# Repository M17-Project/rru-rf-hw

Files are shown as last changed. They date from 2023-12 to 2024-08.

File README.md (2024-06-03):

[][cc-by-nc-sa]

# rru-rf-hw
Remote Radio Unit RF board.

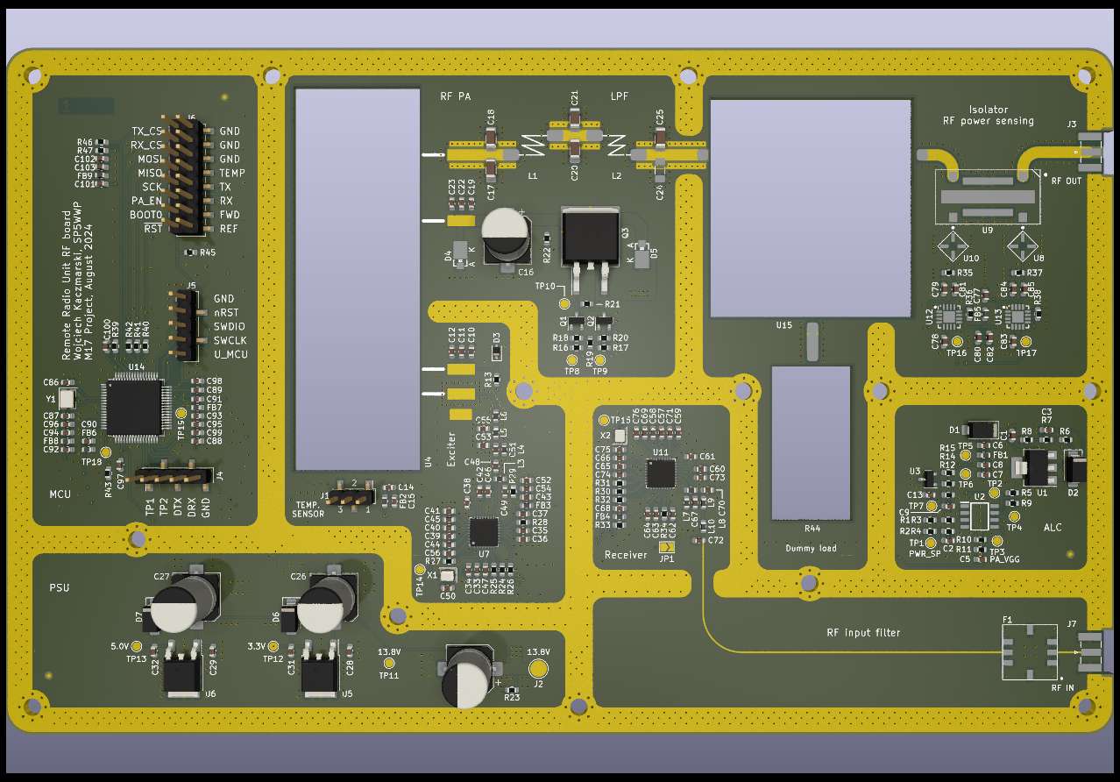
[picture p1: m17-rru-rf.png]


## What is it?
An FM repeater in a milled aluminum chassis. Built around a pair of [CC1200 chips](https://www.ti.com/product/CC1200) from Texas Instruments and an RF power amplifier module.
Revision A with CC1200 RF front-ends supports various FM-based modes, including M17 and AFSK.

## Quick fact sheet
RF power module - [RA60H3847M1](https://www.mitsubishielectric.com/semiconductors/hf/products/datasheet/ra60h3847m1.pdf)<br>
RF output power - 1..60W continuous, up to 80W with lower duty cycle<br>
Frequency range - 420..450MHz<br>
Frequency error - <0.5 ppm over -40 to +85°C range<br>
Supply voltage - 13.8V DC<br>
Power consumption - <150W at 60W RF out<br>
Load mismatch immunity - continuous over the whole VSWR range (built in RF isolator)<br>
Harmonic content - 2nd <-40dBc, 3rd <-55dBc (435MHz at 48.3dBm)<br>
Mode support: analog FM, M17, (A)FSK<br>
Circulator:  WH3538X-1, 400..470MHz (microstrip)<br>
Dummy load: Anaren [J100N50X4B](https://www.mouser.pl/datasheet/2/21/J100N50X4B-3364610.pdf)<br>

## Firmware
A basic, "crash-test" frmware template is available [here](https://github.com/M17-Project/rru-rf-fw).

### Flashing the MCU over UART
- Build the firmware using CubeIDE
- Copy the .bin file over to Raspberry Pi
- Run `stm32flash -v -R -i "-539&-529&539,529,:-539,-529,529" -w rru-rf-fw.bin /dev/ttyAMA0`

In case of problems, see [this](https://github.com/M17-Project/rpi-interface?tab=readme-ov-file#flashing-the-target-device-cc1200-hat) for some additional explanation.

## Chassis
Milled aluminum chassis is required. A reference design can be obtained from a [separate repository](https://github.com/M17-Project/rru-rf-chassis).

## Revision history
### Revision A
Initial revision.

### Revision B
* Switched mode voltage regulators have been replaced with linear.
* Added a buffer between the 40 MHz reference TCXO and transceiver ICs.
* Added bleeder resistors at the RF PA and 13.8V power supply.
* Slightly improved ALC circuit.
* Reduced N-connector cutouts (4.5mm down to 2mm).
* Added decoupling capacitor arrays at both RF PA's supply and VGG pins.
* DA15 connector now has MCU's BOOT0 signal available at pin 13.
* Bodge wire mod is no longer required, as both baseband trigger signals are now routed to the MCU.

### Revision C
* Added a lowpass filter after the RF PA stage
* Added a bandpass filter at the RF input
* TX and RX blocks are now clocked independently
* Pull-down resistor at TP2 (BOOT1)

## License
This work is licensed under a
[Creative Commons Attribution-NonCommercial-ShareAlike 4.0 International License][cc-by-nc-sa].

[][cc-by-nc-sa]

[cc-by-nc-sa]: http://creativecommons.org/licenses/by-nc-sa/4.0/
[cc-by-nc-sa-image]: https://licensebuttons.net/l/by-nc-sa/4.0/88x31.png
[cc-by-nc-sa-shield]: https://img.shields.io/badge/License-CC%20BY--NC--SA%204.0-lightgrey.svg

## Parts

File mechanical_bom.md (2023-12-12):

|Name |PN |Qty |
|---|---|---|
|DA15 connector |DA15S064TLF |1 |
|female N connector |CONN002-W |2 |
|EMI feedthrough filter |2499-003-X5W0-103ZLF |1 |
|M3x5 screw |generic |14 |
|M3x14 screw |generic |4 |
|M3x6 screw |generic |10 |
|M2.5x4 screw |generic |1 |

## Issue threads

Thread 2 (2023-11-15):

RF PA temperature sensor's range extension

sp5wwp, 2023-11-15:
LMT87's temperature range can be extended a bit by supplying it with 5 instead of 3.3V.

sp5wwp, 2024-01-18:
Fixed in 636a110.

Closed 2024-01-18.

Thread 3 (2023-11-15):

Linear voltage regulators instead of switched-mode

sp5wwp, 2023-11-15:
Consider using linear voltage regulators for 3.3 and 5V lines.

sp5wwp, 2024-01-08:
`KF50BDT` and `KF33BDT` are good candidates.

sp5wwp, 2024-01-19:
Fixed in 727ba27.

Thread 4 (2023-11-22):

N connector cutouts

sp5wwp, 2023-11-22:
PCB cutouts are 4.5mm deep now, they can be reduced to 2mm.

Workaround:
Use a 3-4mm long piece of copper wire to solder the N connector's pin to the PCB pad.

sp5wwp, 2024-01-18:
Fixed in 636a110.

Closed 2024-01-18.

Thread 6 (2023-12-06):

Hardware Choices

tomhajjar, 2023-12-06:
1. Is the unit Full or Half Duplex? If Half, why no T/R switch?

2. Why use a bi-directional coupler and log amps on TX output? APC only needs a resistive divider feeding a detector IC like LTC5505.

3. Why use an output isolator? The RA60H3847 can handle fairly high VSWR.

sp5wwp, 2023-12-08:
1. Full duplex with 2 ports. No T/R switch needed.
2. Bi-directional coupler is used to measure SWR.
3. "Fairly high SWR" is not enough, we wanted the output to be bulletproof.

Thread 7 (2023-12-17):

RF input and output stage improvements

sp5wwp, 2023-12-17:
1. Replace `L11`, `C64`, `C63`, and `L10` with a legit bandpass (or lowpass) filter - RBP-440+, LFCN-490+?
2. Put an ESD protection device close to the RX N connector - SESD0402X1UN?
3. Add a lowpass filter between the RF PA and circulator.

sp5wwp, 2024-01-18:
This is for rev. C.

sp5wwp, 2024-03-13:
3. is being worked on.

sp5wwp, 2024-04-04:
3. Done in [4926947](https://github.com/M17-Project/rru-rf-hw/commit/4926947ab17ab5175633e2806dfe3566c8cfa8d8).

sp5wwp, 2024-04-05:
All but 2 fixed in [3db3335](https://github.com/M17-Project/rru-rf-hw/commit/3db3335a4e87a1f32e75a32e3673d100e865a612).

Closed 2024-04-05.

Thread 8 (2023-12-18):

Sampling rate issue

sp5wwp, 2023-12-18:
MCU has to know when to send/read baseband samples from the transceivers. Now, the sample clock is run at the MCU side at 24kHz, and causes occasional sample drops and desynchronization.

Solution (updated Jan 5, 2024):
Connect GPIO2 pin of the transmitting CC1200s to the MCU's EXTI pins, thus letting the TX dictate the baseband transfer speed.
TX GPIO2 (pin 4 of `U7`) -> MCU PA8 (pin 41 of `U14`)

sp5wwp, 2023-12-19:
New firmware has a `#define` to handle the bodge wire mod.

ferdem, 2023-12-19:
unsubscribe

Wojciech Kaczmarski ***@***.***>, 19 Ara 2023 Sal, 16:44
tarihinde şunu yazdı:

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

--
Fatih Erdem

sp5wwp, 2024-01-05:
The new `rpi-interface` branch supports the bodge wire mod without the need of having any #defines.

MCU passes baseband samples to the transmitter at the programmed rate (1.5*16=24kHz), trigger signal is provided by the CC1200. The receiver's `CLKEN_CFM` clock signal is always about 75.7582kHz, regardless of the sample rate setting. Baseband samples from the receiver are therefore read at a rate dictated by TIM7.

sp5wwp, 2024-01-18:
TX sample clock fixed in 636a110.

Closed 2024-01-18.

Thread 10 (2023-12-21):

nRST line pulldown

sp5wwp, 2023-12-21:
Increase R44 to 47..100k.

sp5wwp, 2024-01-18:
Fixed in 636a110. Additionally, 2 other resistors were changed to 22k (R45 and R46).

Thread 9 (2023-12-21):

ALC stability issue above 40dBm

sp5wwp, 2023-12-21:
Problem:
Output level instability, probably caused by insufficient PA drive.

Fix:
- Remove C2 (or replace by lower value capacitor, like 220pF).
- Bypass R5 with a 100nF capacitor to extend ramp-up time.
- Add MMIC preamplifier between the exciter and PA - [GVA-83+](https://www.minicircuits.com/pdfs/GVA-83+.pdf) looks OK.

sp5wwp, 2024-01-01:
Add an RC lowpass between U1B and VGG.

sp5wwp, 2024-01-18:
636a110 has a potential fix. Might reopen this issue if the problem persists.

Closed 2024-01-18.

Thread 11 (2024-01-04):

BOOT0 line at the DA15 connector

sp5wwp, 2024-01-04:
It would be nice to expose STM32's BOOT0 pin at the DA15 connector to enable remote MCU reprogramming.

sp5wwp, 2024-01-18:
Fixed in 636a110.

Closed 2024-01-18.

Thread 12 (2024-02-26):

Fix programming over USART1

sp5wwp, 2024-02-26:
Since the `TP2` (PB2, pin 28) is shared with `BOOT1`, add a pull-down resistor there.

sp5wwp, 2024-04-04:
Fixed with [4926947](https://github.com/M17-Project/rru-rf-hw/commit/4926947ab17ab5175633e2806dfe3566c8cfa8d8).

Closed 2024-04-04.

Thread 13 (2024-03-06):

XOSC_Q1 pins left floating

sp5wwp, 2024-03-06:
Connect `XOSC_Q1` pins of both TX and RX CC1200 to GND, as per datasheet, page 6:
`Crystal oscillator pin 1 (must be grounded if a TCXO or other external clock connected to EXT_XOSC is used)`

sp5wwp, 2024-04-04:
Fixed with [4926947](https://github.com/M17-Project/rru-rf-hw/commit/4926947ab17ab5175633e2806dfe3566c8cfa8d8).

Closed 2024-04-04.

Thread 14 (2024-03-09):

CC1200 clocking issues

sp5wwp, 2024-03-09:
40MHz signal reaching CC1200 transceivers has an average rising time of 2.7ns, which exceeds 2ns limit set by the datasheet (see [p. 15](https://www.ti.com/lit/ds/symlink/cc1200.pdf?ts=1709928554703)).

Symptoms: CW signals have spurs at 27..40kHz (both sidebands) at about -40dBc.

Workaround: connect the TCXO's output through a 9.1pF capacitor straight to TX's pin 32. This requires cutting the path between that pin and clock buffer's output.

sp5wwp, 2024-03-13:
One possible solution to that would be to use 2 TCXOs - one for each CC1200.

sp5wwp, 2024-04-04:
Fixed with [4926947](https://github.com/M17-Project/rru-rf-hw/commit/4926947ab17ab5175633e2806dfe3566c8cfa8d8).

Closed 2024-04-04.

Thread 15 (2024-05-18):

RS-485

sp5wwp, 2024-05-18:
Use RS-485 instead of raw 3.3V UART for improved noise immunity.

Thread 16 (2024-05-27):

RF lowpass filter - proposed values

sp5wwp, 2024-05-27:
`L1`, `L2` as described in the schematic:
0.8 mm silver plated copper wire
3 turns
3.2 mm inner diameter
~4 mm length
Resulting inductance should be around 24nH

`C17`, `C18` plus PCB trace stray capacitance (3.8 pF measured): should add up to 6.8 pF. Proposed values: 1.5 + 1.5 pF.
`C20`, `C21` plus PCB trace stray capacitance (3.3 pF measured): should add up to 13 pF. Proposed values: 8.2 + 1.5 pF.
`C24`, `C25` plus PCB trace stray capacitance (4 pF measured): should add up to 6.8 pF. Proposed value: 2.7 pF.

PNs:
`12062A2R7CAT2A` - MLCC, 200V 2.7pF C0G 1206 0.25pF tol.
`12067A1R5CAT2A` - MLCC, 500V 1.5pF C0G 1206 0.25pF tol.
`12067A8R2BAT2A` - MLCC, 500V 8.2pF C0G 1206 0.1pF tol.

sp5wwp, 2024-05-27:
If the values are OK, I'll update the schematic accordingly.

sp5wwp, 2024-08-08:
Added in [f473ff9](https://github.com/M17-Project/rru-rf-hw/commit/f473ff9adecd40cb060c2f3618910c76df8fe21e).

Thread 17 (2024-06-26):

RF PA bias limiting Zener diode

sp5wwp, 2024-06-26:
`D3`'s Zener voltage is 5.1V, maybe it would be wise to replace it with a 4.3 or 4.7V.

sp5wwp, 2024-08-08:
Maximum Vgg is 6V, we could keep the 5.1V Zener diode, but I'm replacing it with 4.7V `MM3Z4V7ST1G`.

Closed 2024-08-08.

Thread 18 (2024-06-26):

License question

sedlund, 2024-06-26:
I see this project is using the 'CC Attribution-NonCommercial-ShareAlike 4.0 International' license.  This is not an OSI approved Open Source license.

M17 project on it's web page says it is an open source project.

How was this license chosen for this project?

When someone donates to M17 can they choose to only fund open source projects?  Is this documented anywhere?

sp5wwp, 2024-06-26:
Thanks for your comments.

>This is not an OSI approved Open Source license.
It doesn't mean that it's not open source. Is the documentation/code available for free to anyone? Yes - for me it's open source.

>M17 project on it's web page says it is an open source project.
Because it is. All our work is available to the general public for free.

>How was this license chosen for this project?
I picked one I liked the most at that time. Since I'm the sole author, I can change them in the future however I desire.

>When someone donates to M17 can they choose to only fund open source projects? Is this documented anywhere?
When donating, the donor gives us a certain amount of money, to sustain the *whole* Project. I don't think our fiscal sponsor allows for funds earmarking per donation.

sp5wwp, 2024-06-26:
`Open source is source code that is made freely available for possible modification and redistribution.`

Which part of this sentence do we violate?

sedlund, 2024-06-26:
Specificlaly the current license states:

```
Section 2 -- Scope.

  a. License grant.

       1. Subject to the terms and conditions of this Public License,
          the Licensor hereby grants You a worldwide, royalty-free,
          non-sublicensable, non-exclusive, irrevocable license to
          exercise the Licensed Rights in the Licensed Material to:

            a. reproduce and Share the Licensed Material, in whole or
               in part, for NonCommercial purposes only; and

            b. produce, reproduce, and Share Adapted Material for
               NonCommercial purposes only.
```

This violates the requirements of the open source definition against discrimination of fields of endeavor - parts 5 and 6 of the [open source definition](https://opensource.org/osd).

sp5wwp, 2024-06-26:
OK: 5. is not violated, while 6. is, deliberately (non-commercial clause). This is exactly how I wanted it to be. Do you have any further comments or questions?

sedlund, 2024-06-26:
I appreciate the clarification.

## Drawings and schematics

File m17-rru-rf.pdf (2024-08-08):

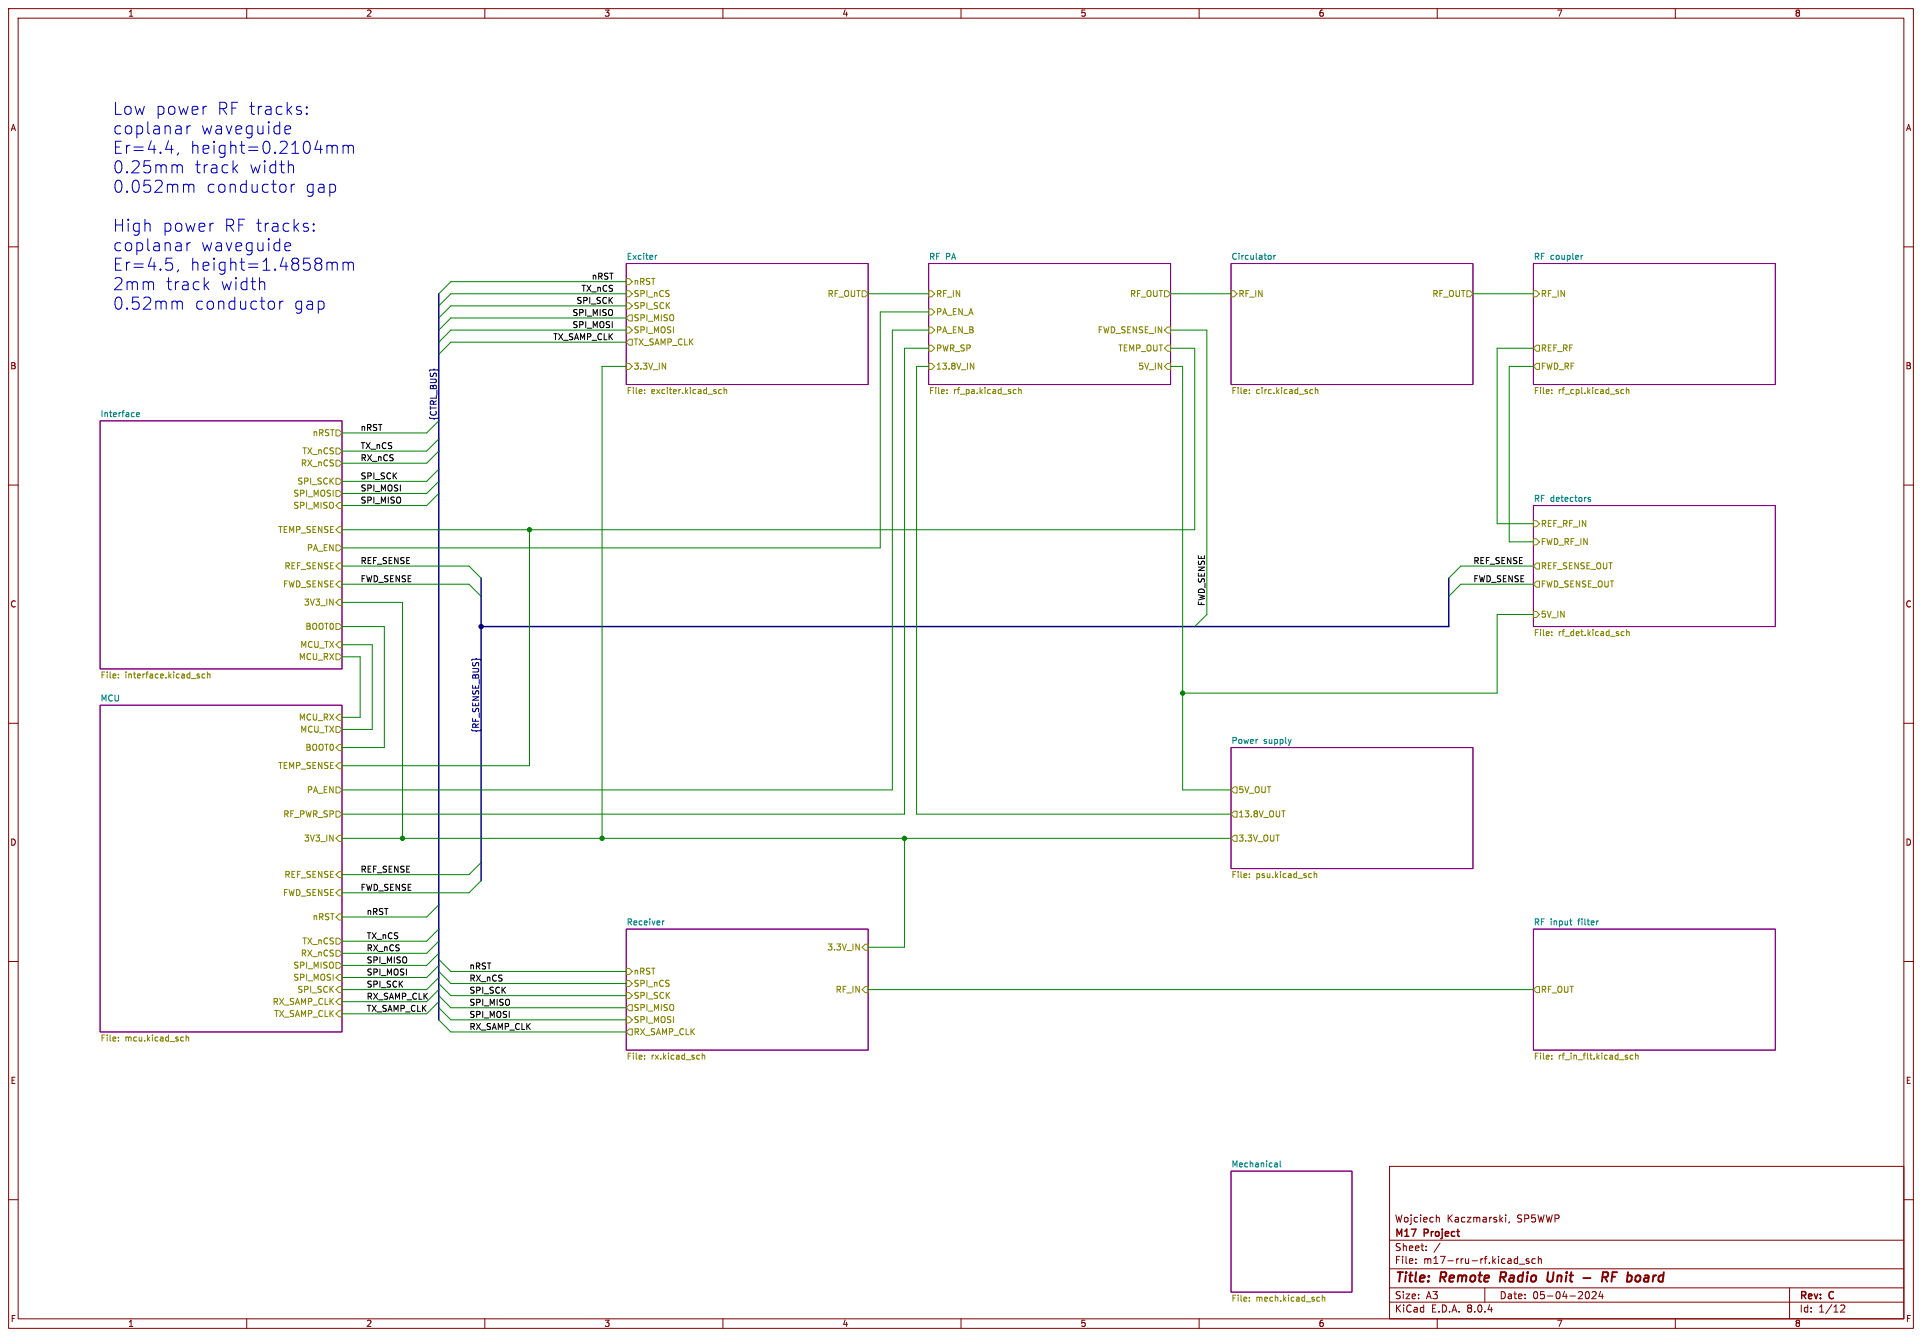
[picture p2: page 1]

nRST SPI_SCK RX_nCS Low power RF tracks:
coplanar waveguide
Er=4.4, height=0.2104mm
0.25mm track width

High power RF tracks:
Er=4.5, height=1.4858mm
2mm track width

5V_OUT Power supply File: psu.kicad_sch

Id: 1/12 Title: Remote Radio Unit - RF board

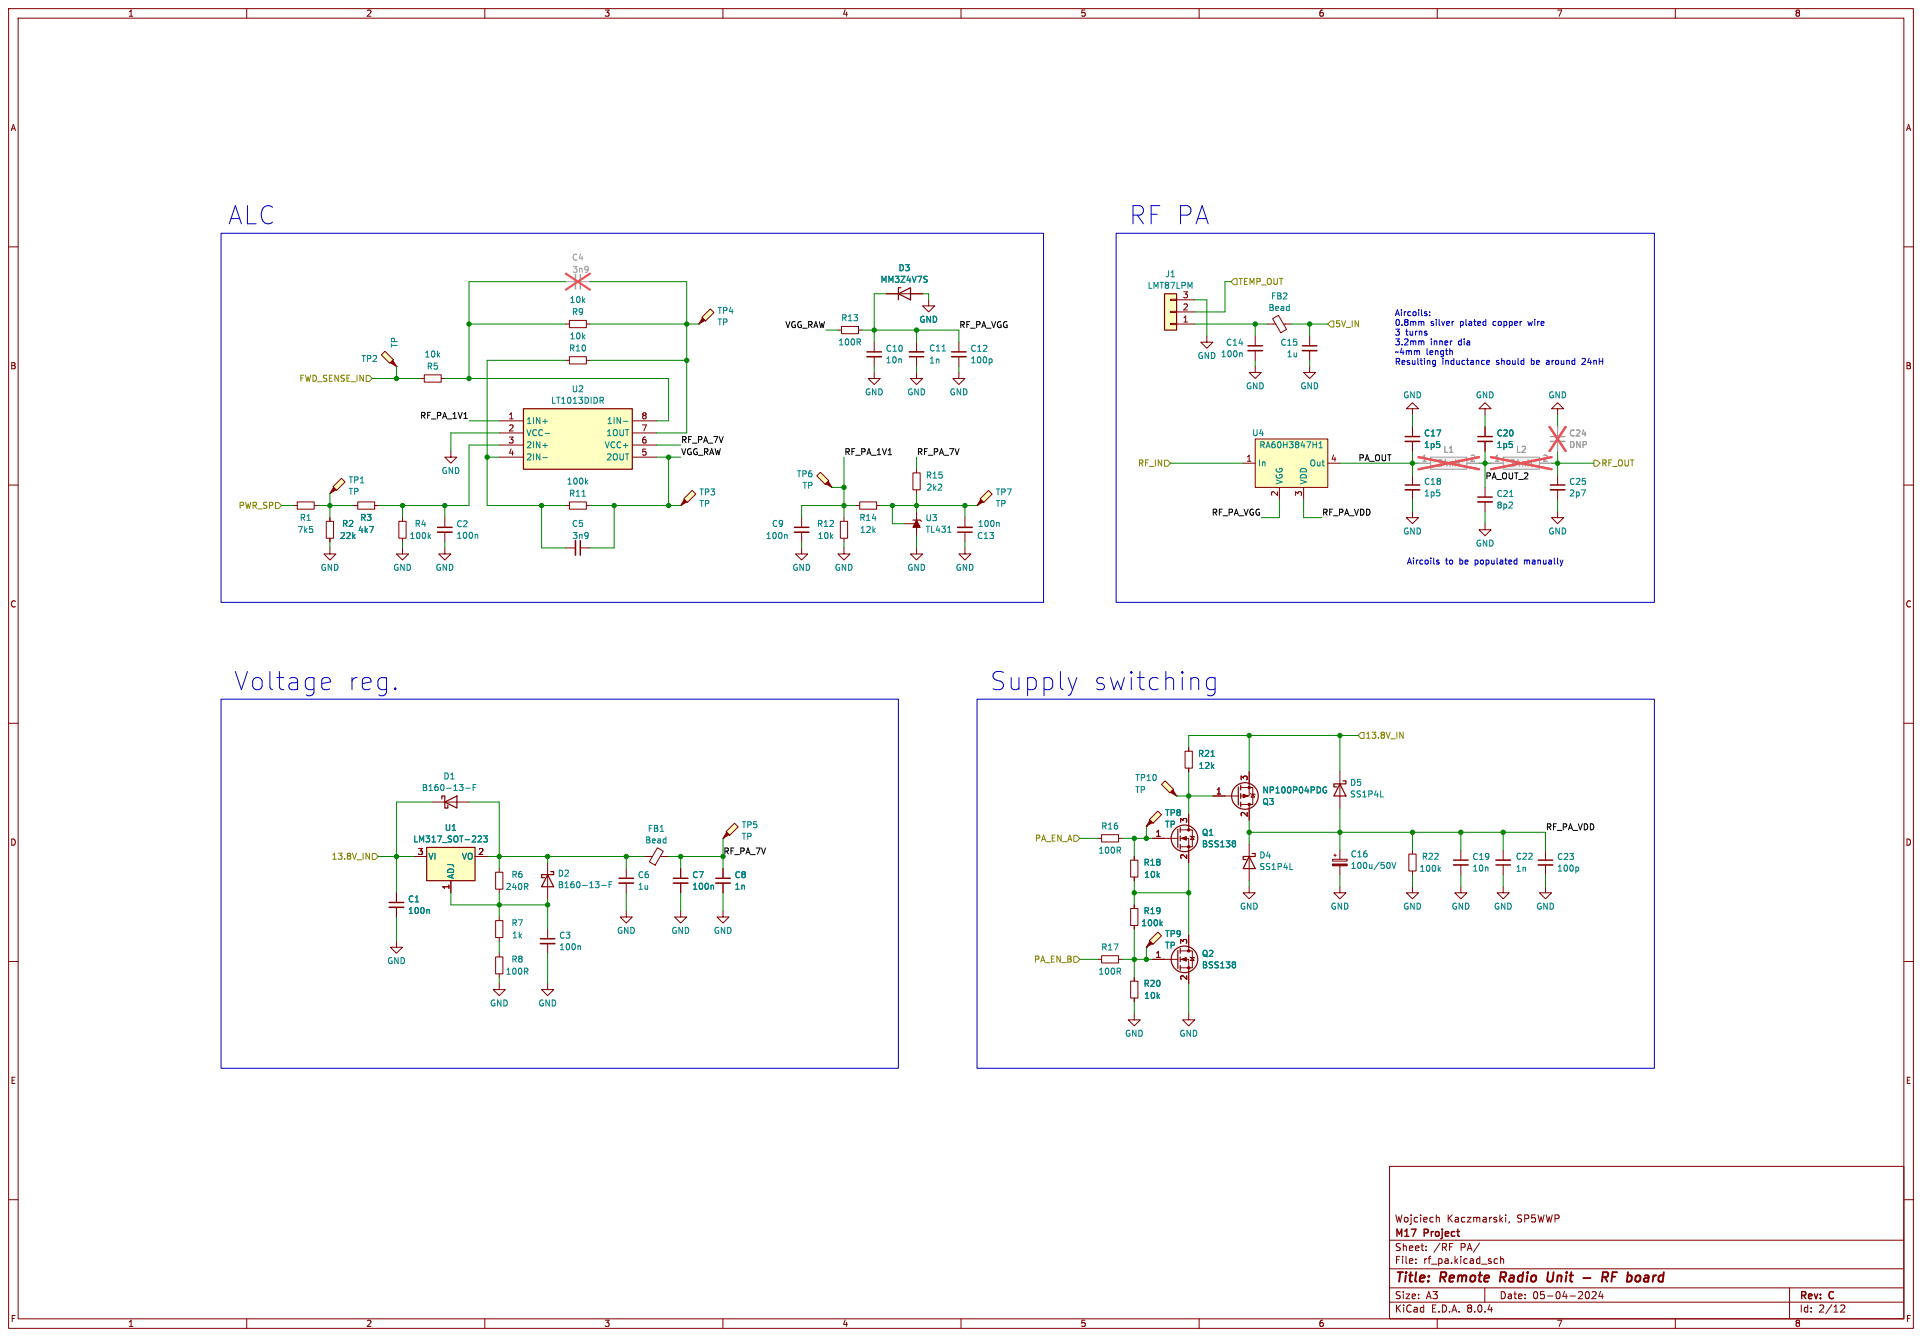
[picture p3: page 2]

Aircoils: 0.8mm silver plated copper wire

3 turns 3.2mm inner dia ~4mm length

Id: 2/12 Title: Remote Radio Unit - RF board

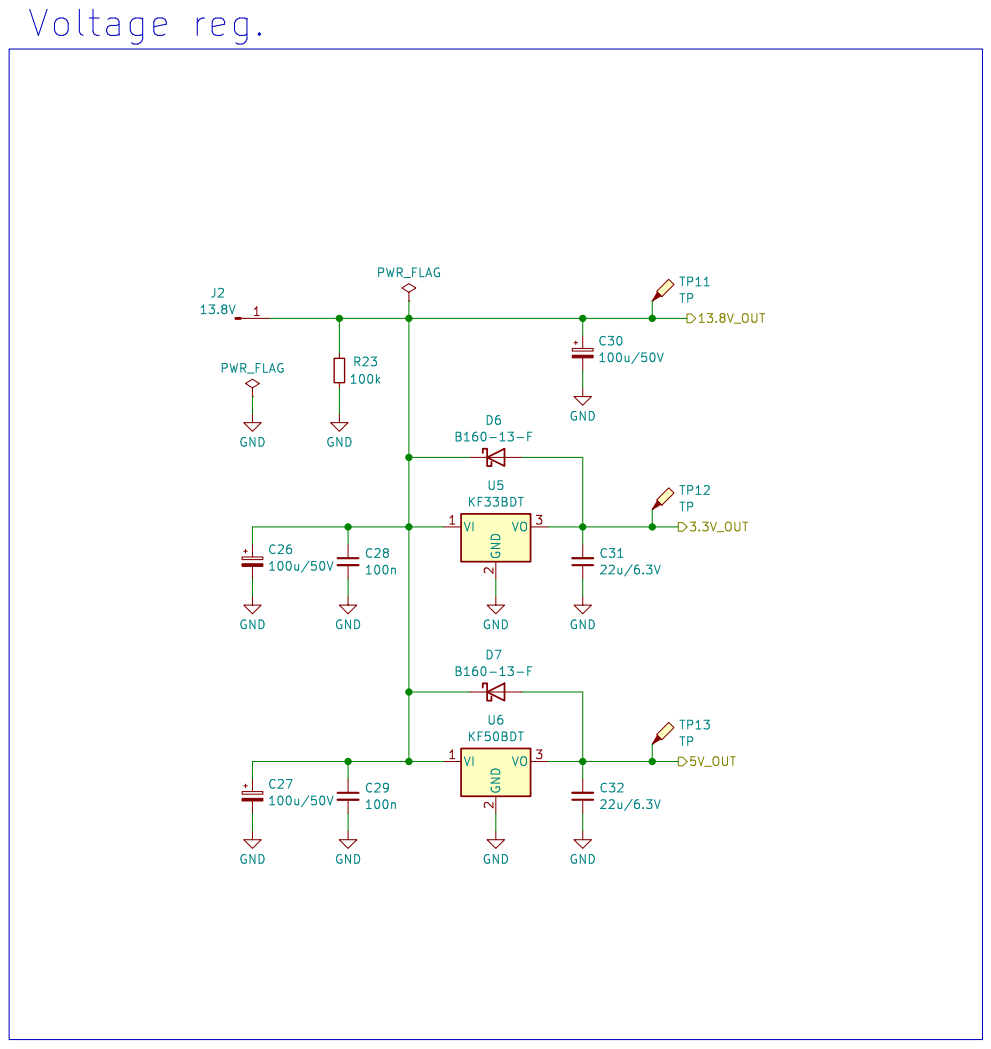
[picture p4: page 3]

2 VO 3 U5 KF33BDT GND GND GND
100u/50V GND

Id: 3/12 Title: Remote Radio Unit - RF board

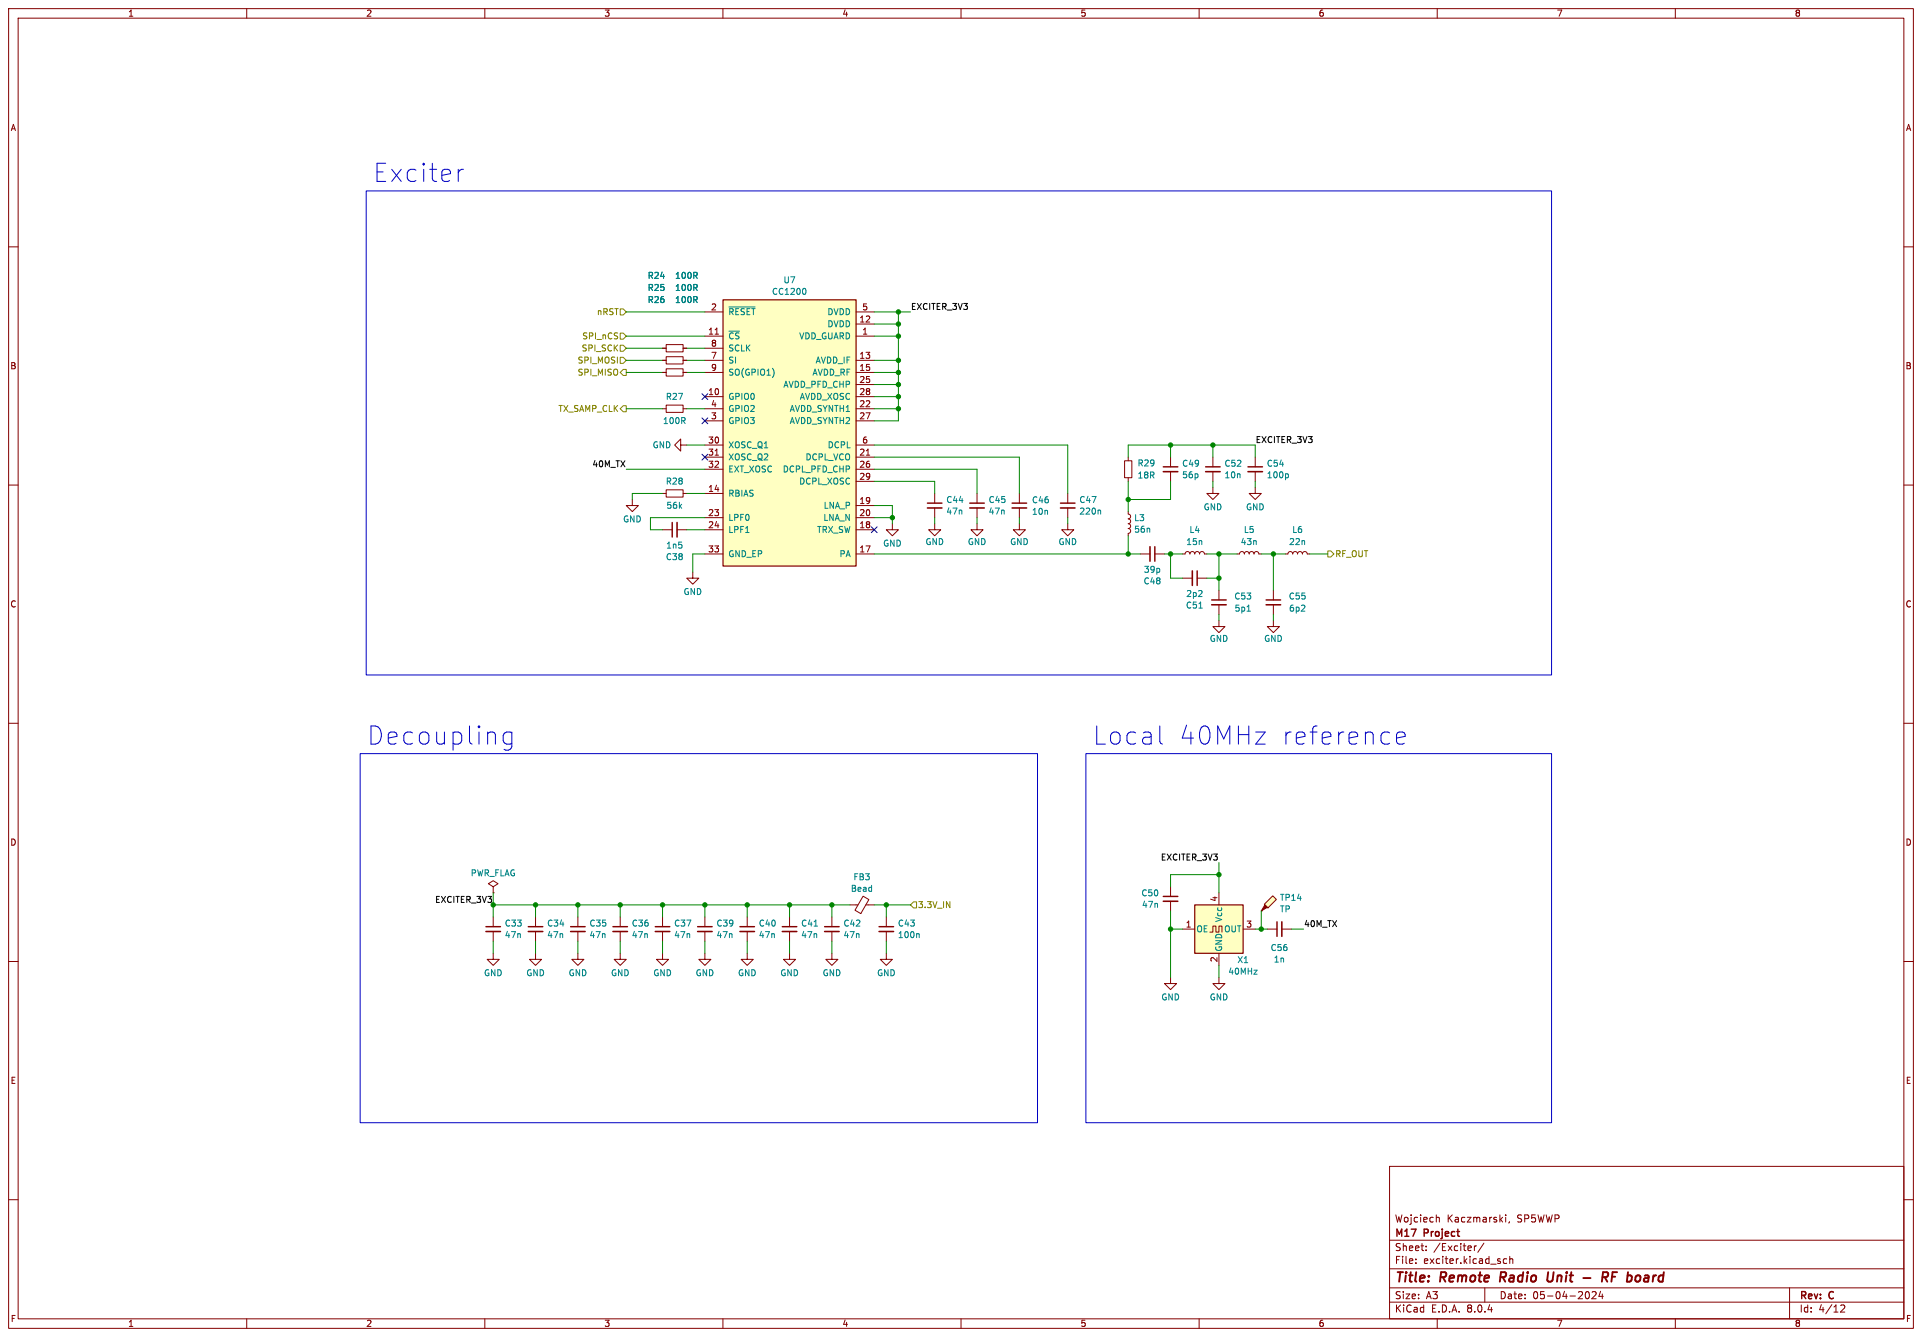
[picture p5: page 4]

Id: 4/12 Title: Remote Radio Unit - RF board

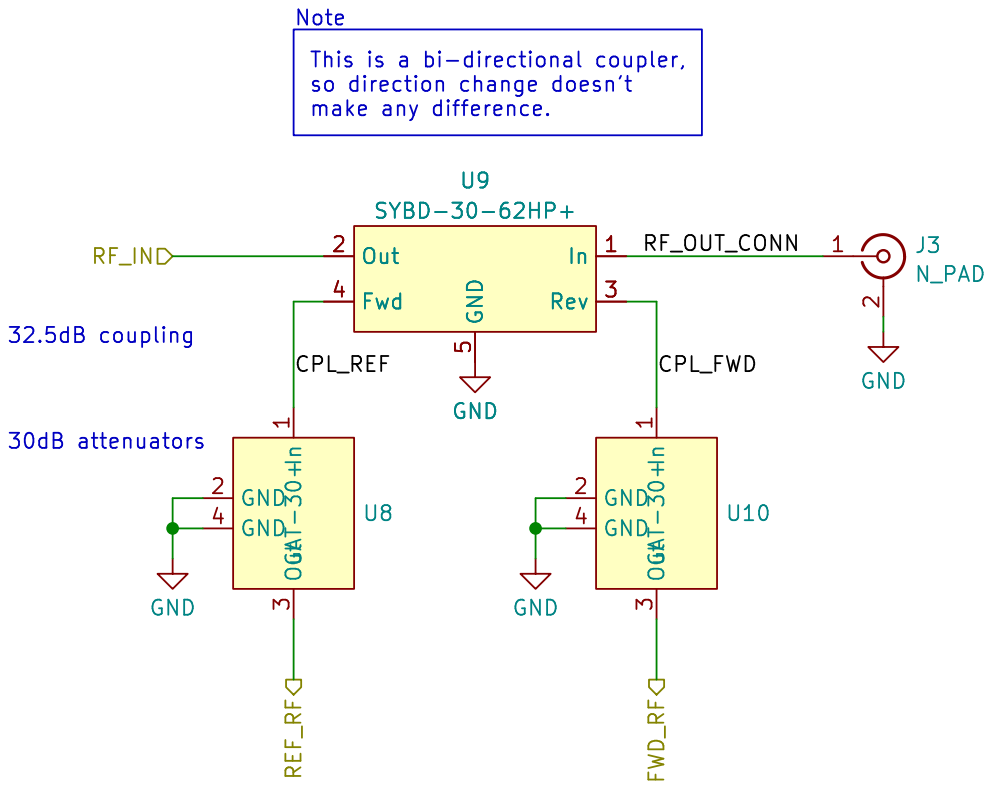
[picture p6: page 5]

1 GND 2 Out 3 GND 4 U8 GAT-30+ FWD_RF RF_IN REF_RF CPL_REF CPL_FWD

1 GND 2 Out 3 GND 4 U10 GAT-30+ GND

Id: 5/12 Title: Remote Radio Unit - RF board

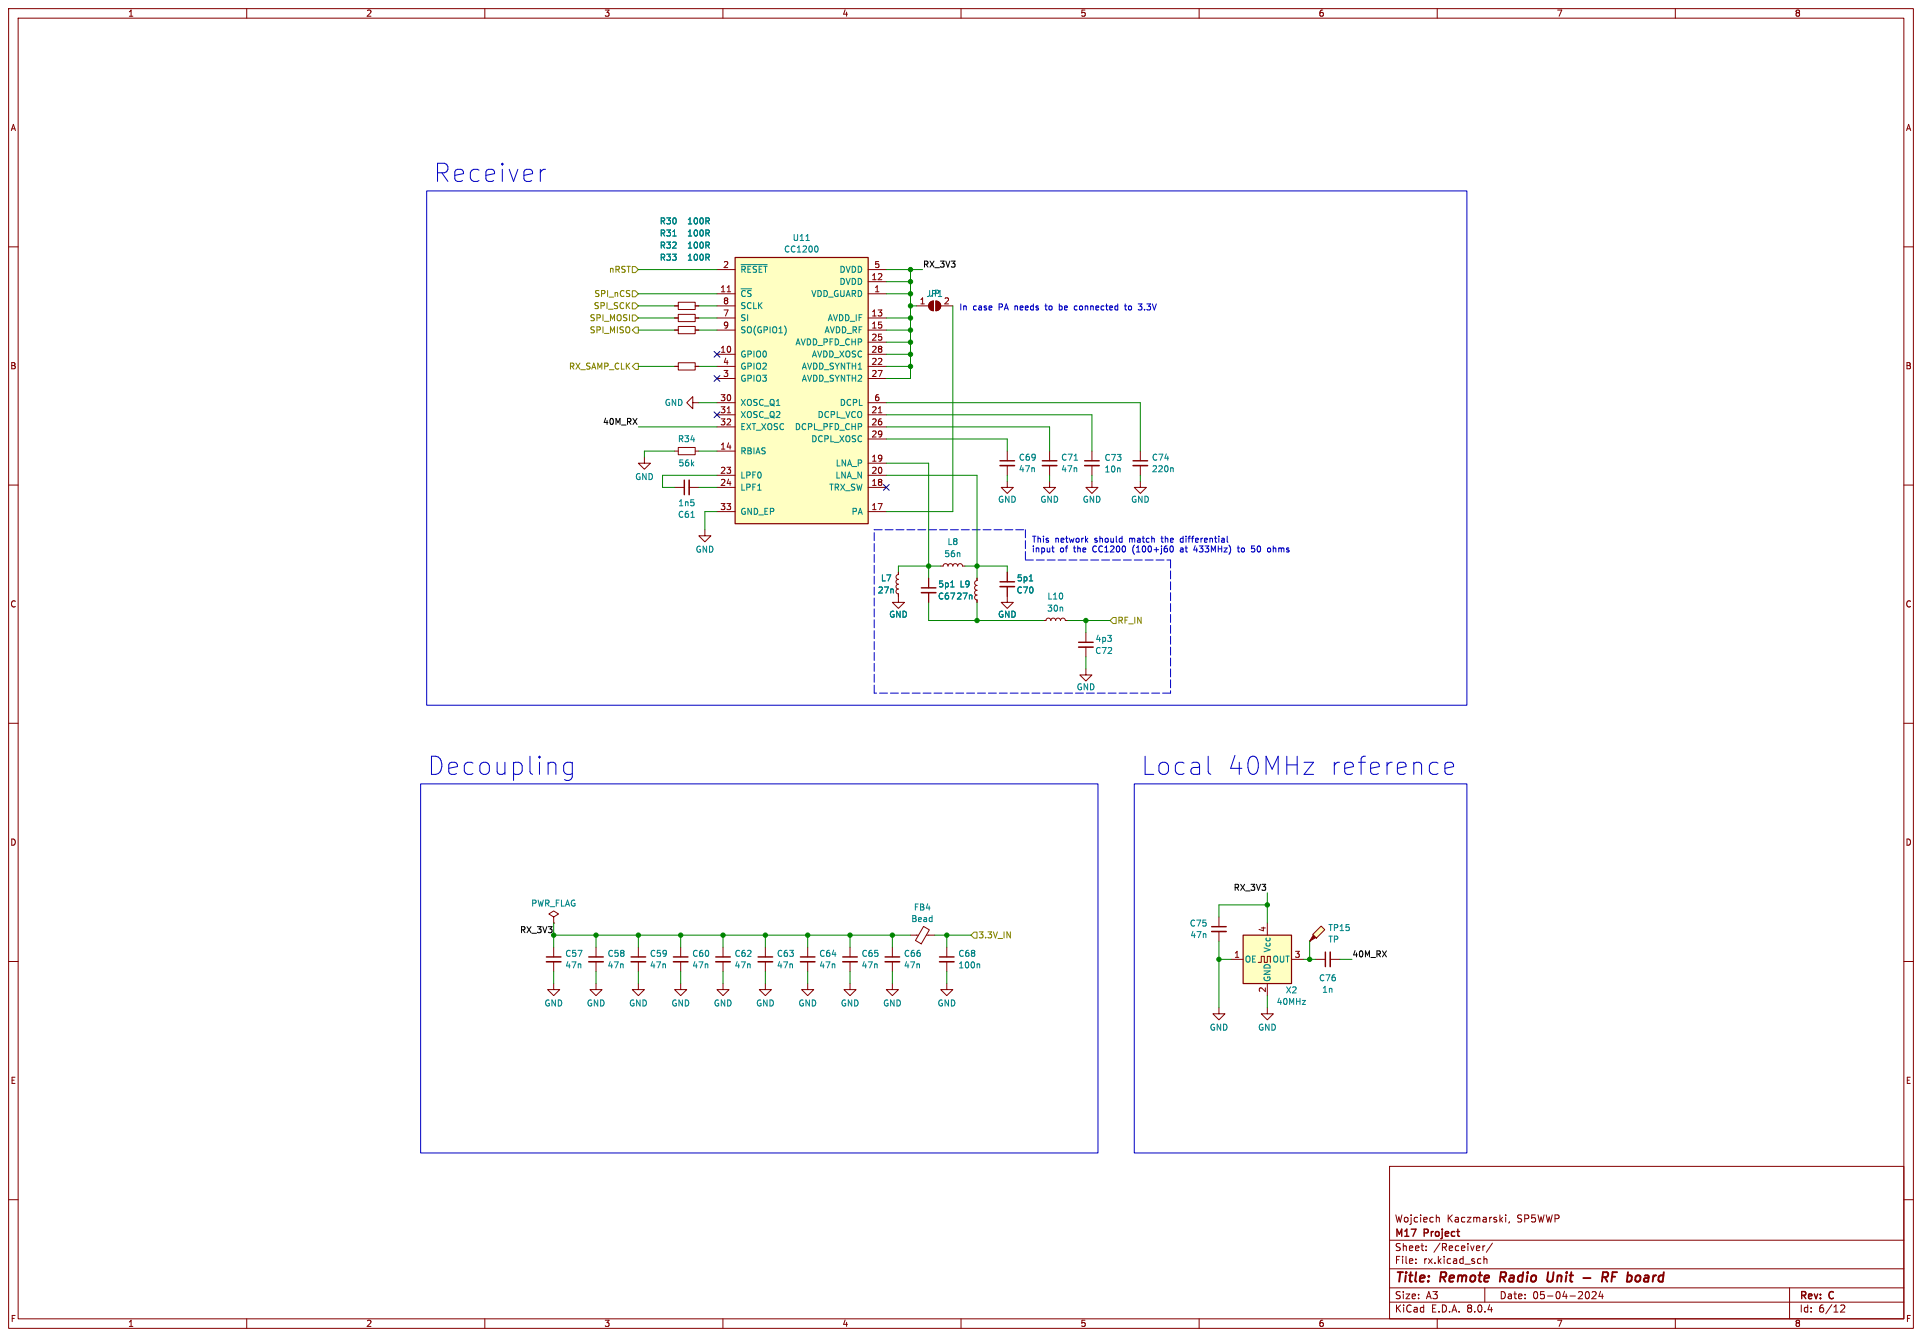
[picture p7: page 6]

This network should match the differential

Id: 6/12 Title: Remote Radio Unit - RF board

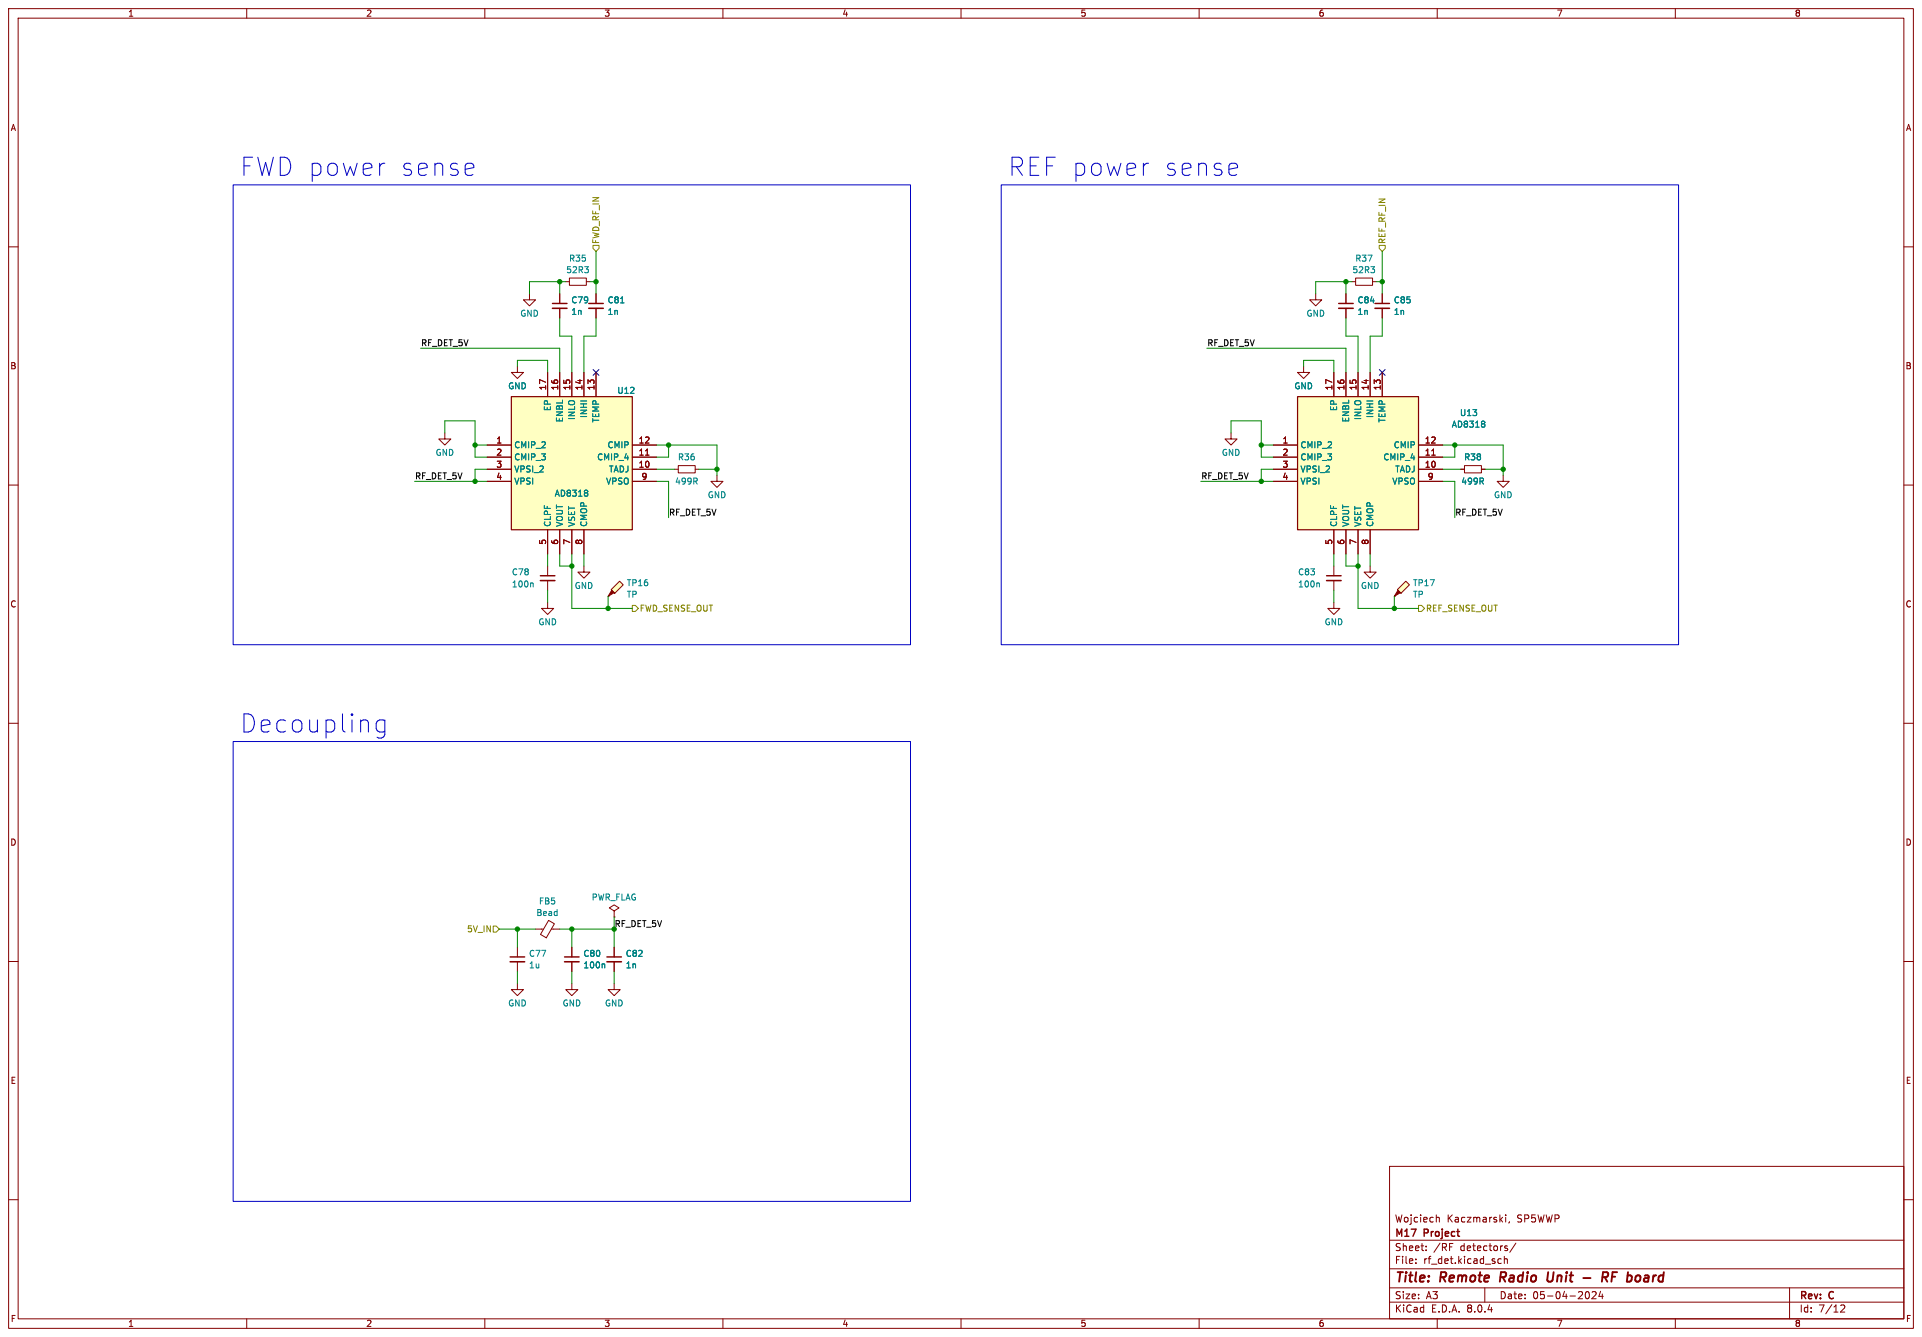
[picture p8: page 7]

Id: 7/12 Title: Remote Radio Unit - RF board

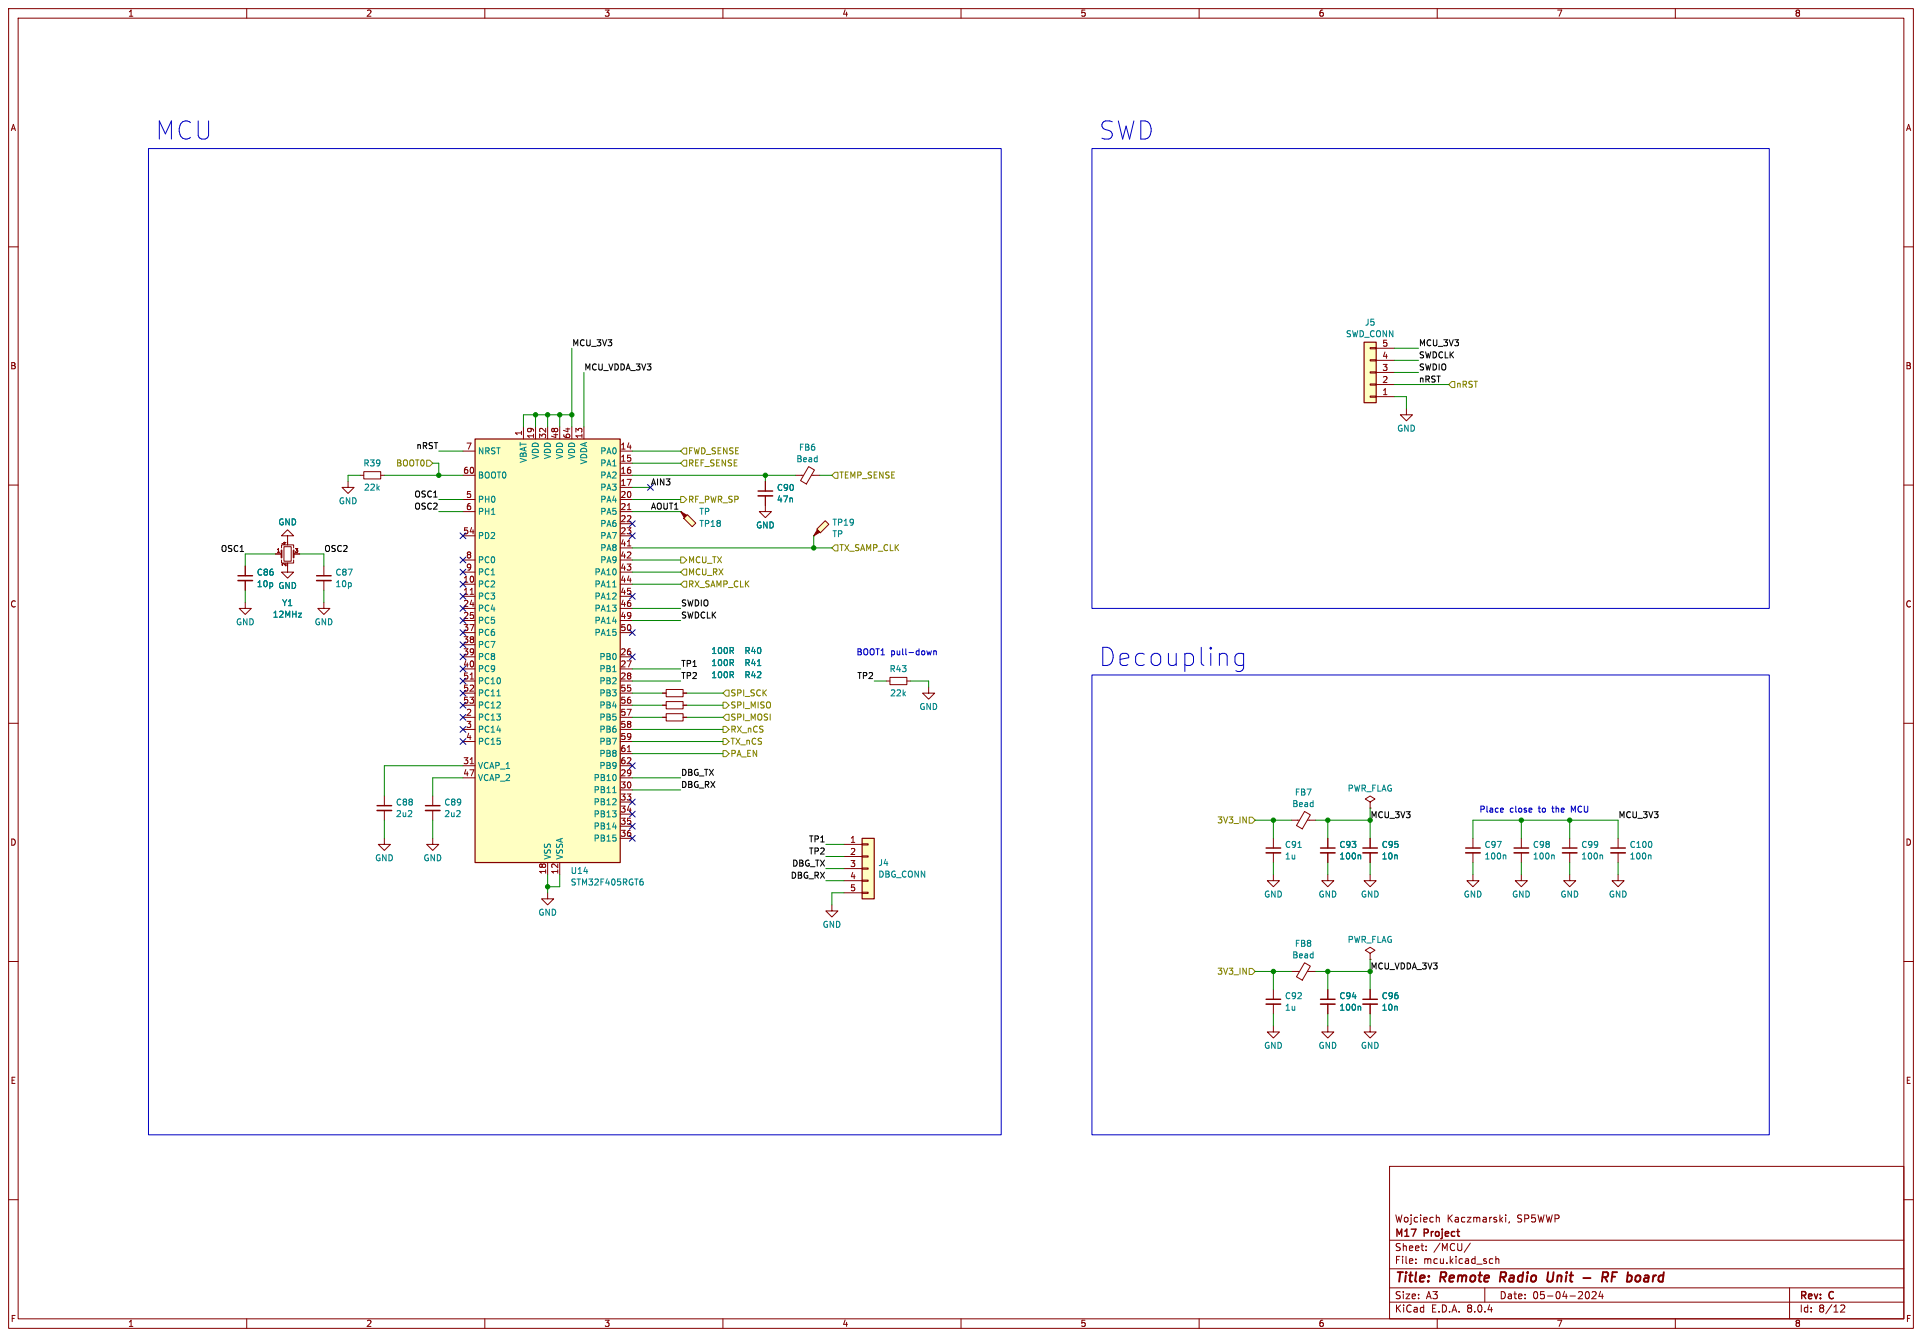
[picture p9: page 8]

1 PC2 10 PC3 11 VSSA 12 VDDA 13 PA0 14 PA1 15 PA2 16 PA3 17 VSS 18 VDD 19 PC13 2 PA4 20 PA5 21 PA6 22 PA7 23 PC4 24 PC5 25 PB0 26 PB1 27 PB2 28 PB10 29 PC14 3 PB11 30 VCAP_1 31 VDD 32 PB12 33 PB13 34 PB14 35 PB15 36 PC6 37 PC7 38 PC8 39 PC15 4 PC9 40 PA8 41 PA9 42 PA10 43 PA11 44 PA12 45 PA13 46 VCAP_2 47 VDD 48 PA14 49 PH0 5 PA15 50 PC10 51 PC11 52 PC12 53 PD2 54 PB3 55 PB4 56 PB5 57 PB6 58 PB7 59 PH1 6 BOOT0 60 PB8 61 PB9 62 VDD 64 NRST 7 PC0 8 PC1 9 U14 STM32F405RGT6 C86

Place close to the MCU

Id: 8/12 Title: Remote Radio Unit - RF board

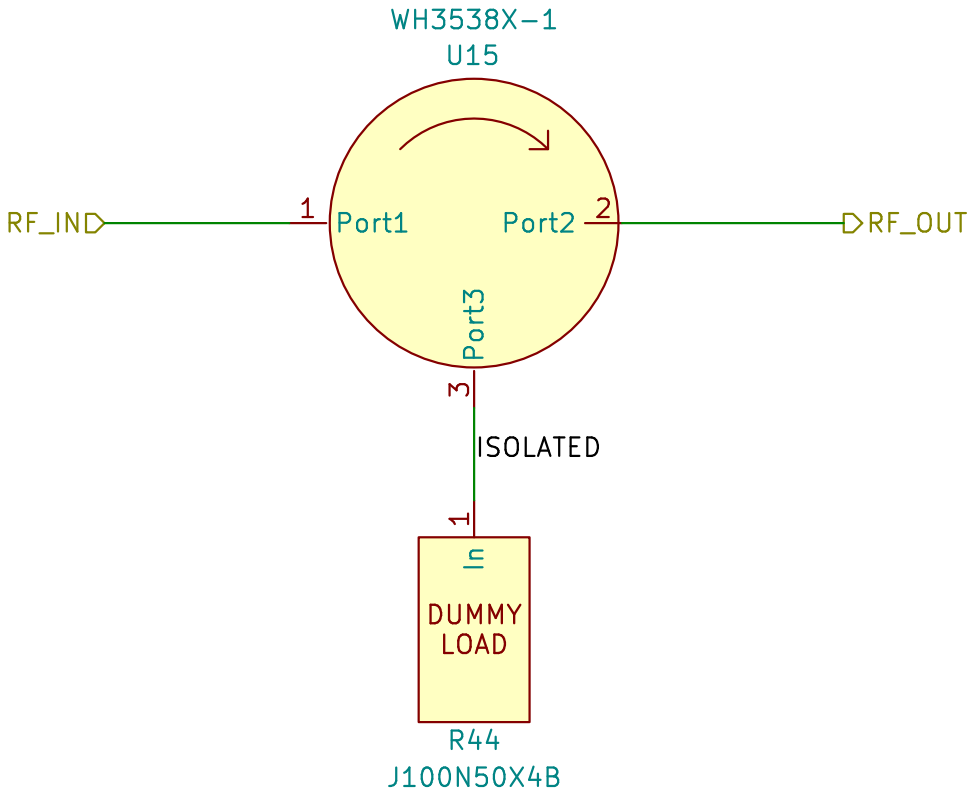
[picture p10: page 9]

Id: 9/12 Title: Remote Radio Unit - RF board

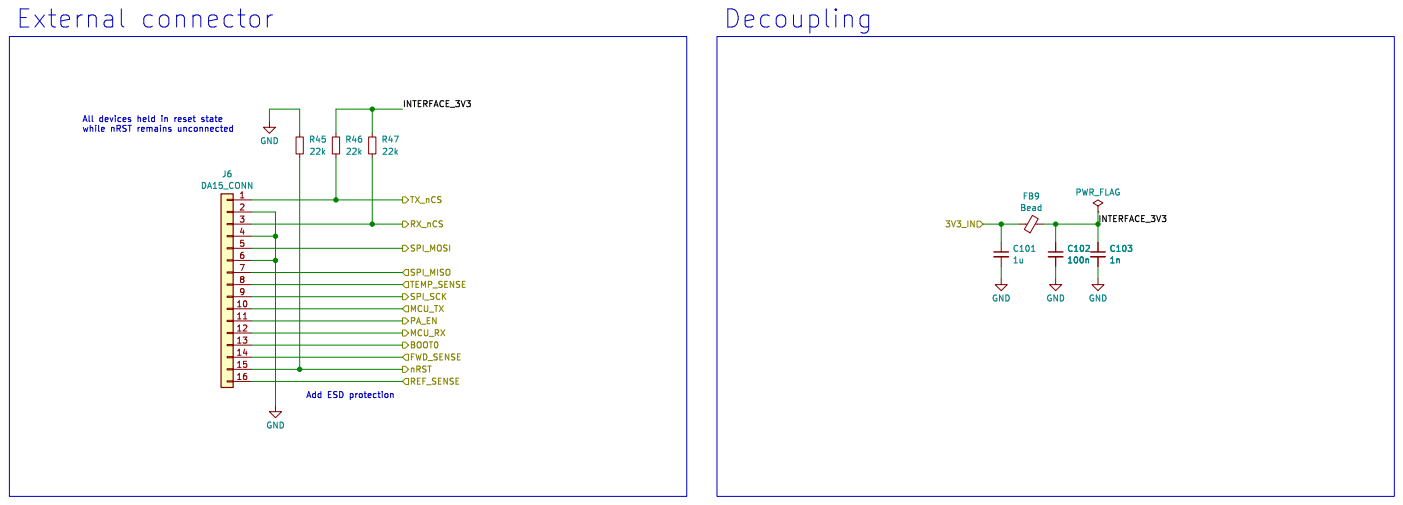
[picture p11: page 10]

Id: 10/12 Title: Remote Radio Unit - RF board

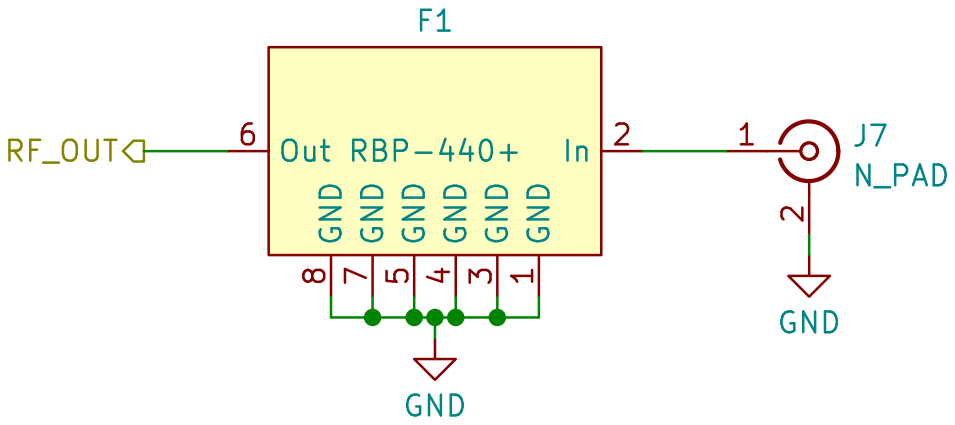
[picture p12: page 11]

Id: 11/12 Title: Remote Radio Unit - RF board

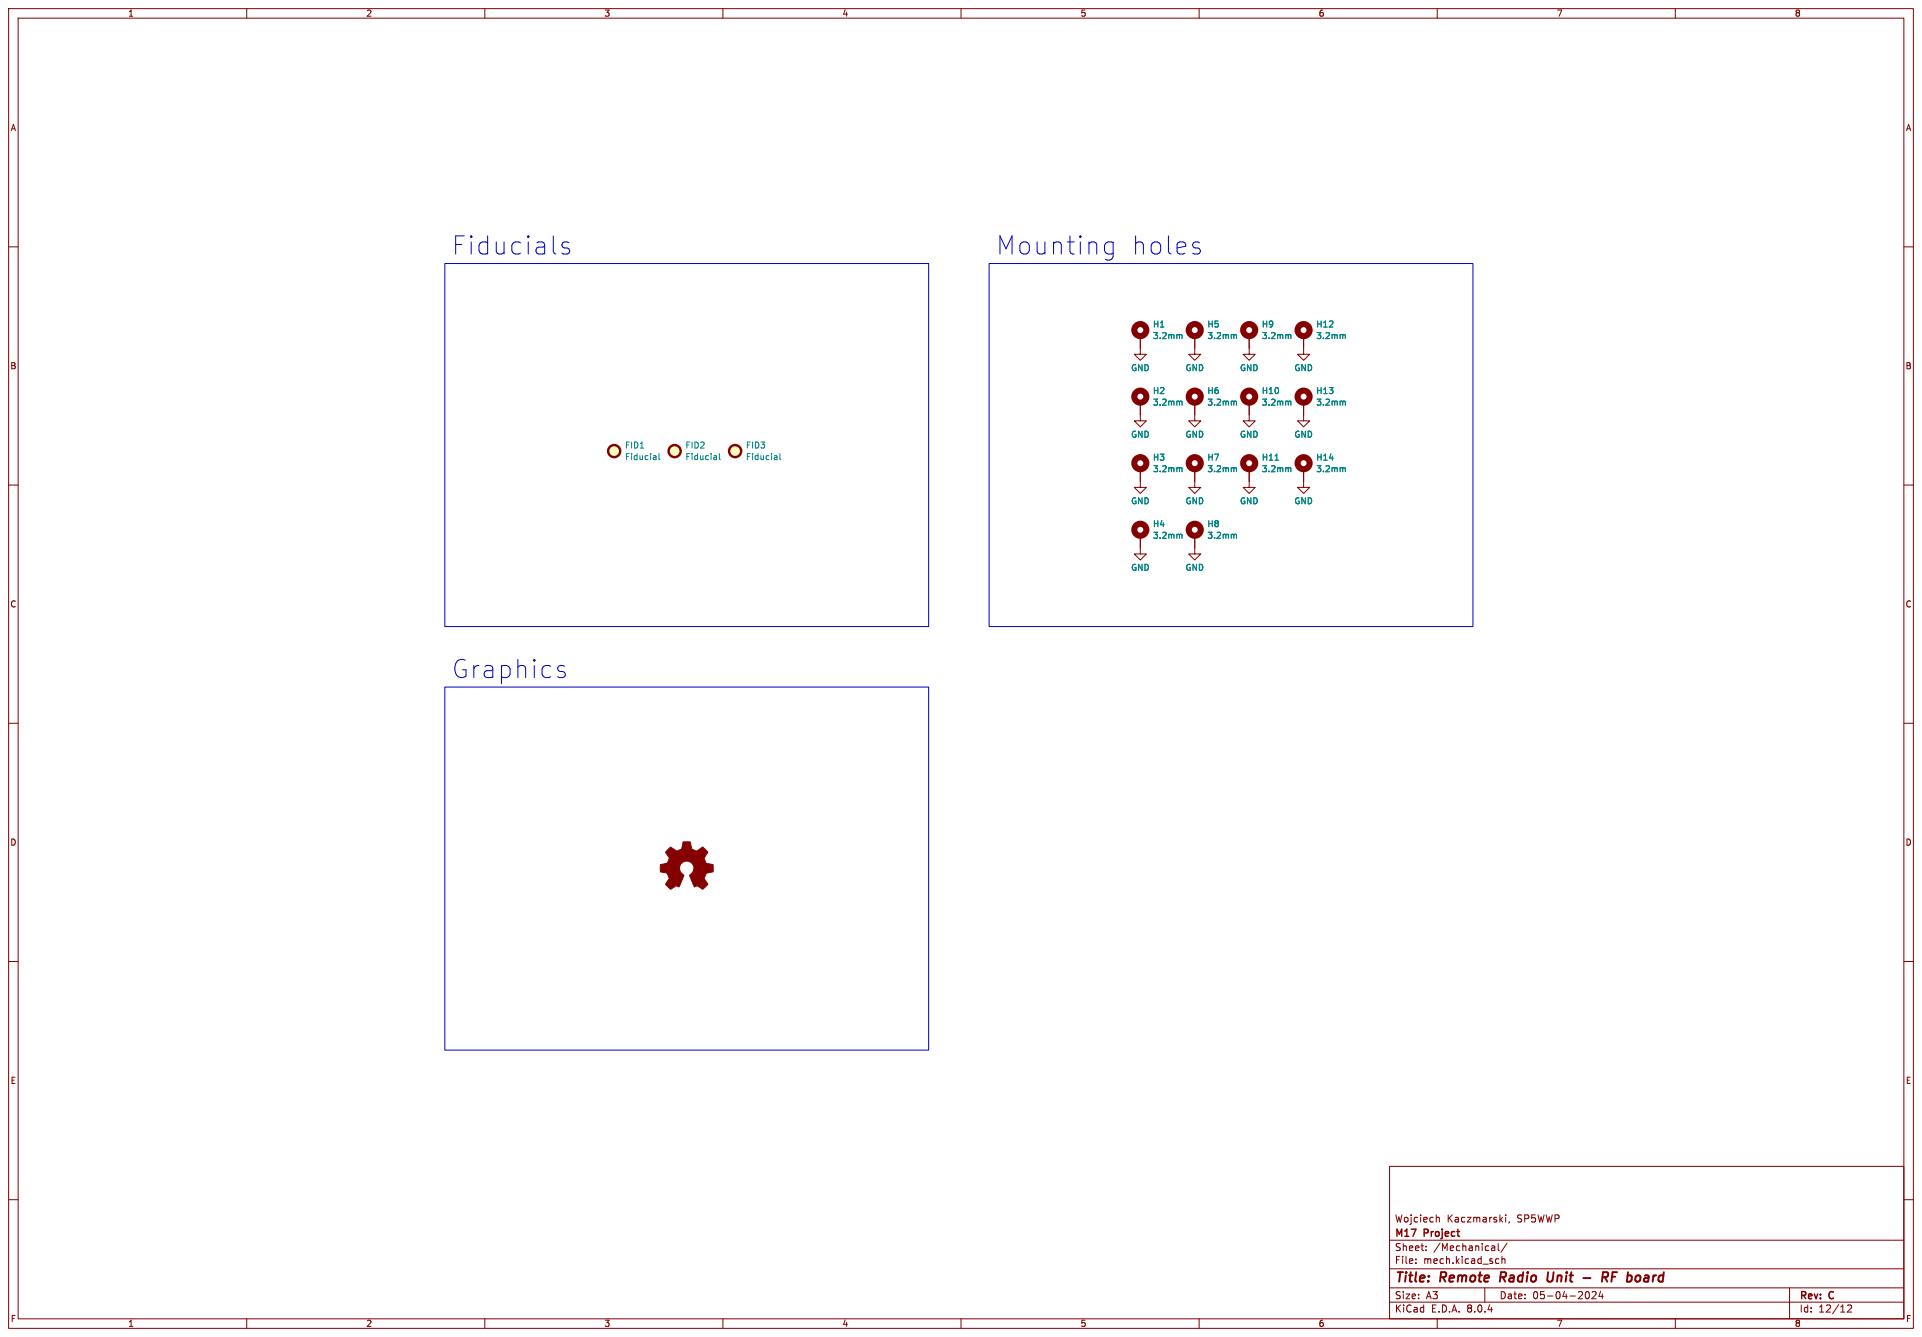
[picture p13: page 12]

Id: 12/12 Title: Remote Radio Unit - RF board

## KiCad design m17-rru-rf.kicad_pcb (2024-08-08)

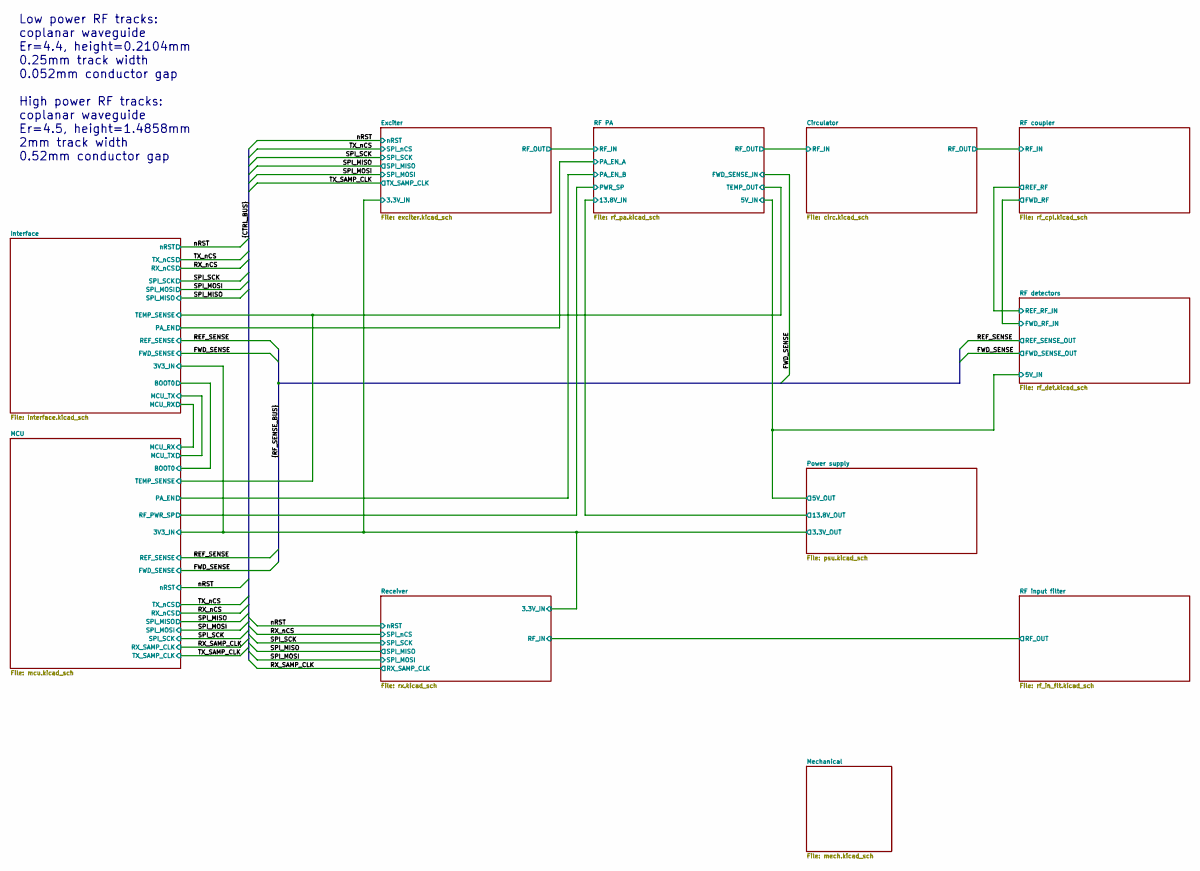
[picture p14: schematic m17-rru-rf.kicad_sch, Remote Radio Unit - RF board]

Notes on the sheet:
Low power RF tracks: coplanar waveguide Er=4.4, height=0.2104mm 0.25mm track width 0.052mm conductor gap High power RF tracks: coplanar waveguide Er=4.5, height=1.4858mm 2mm track width 0.52mm conductor gap

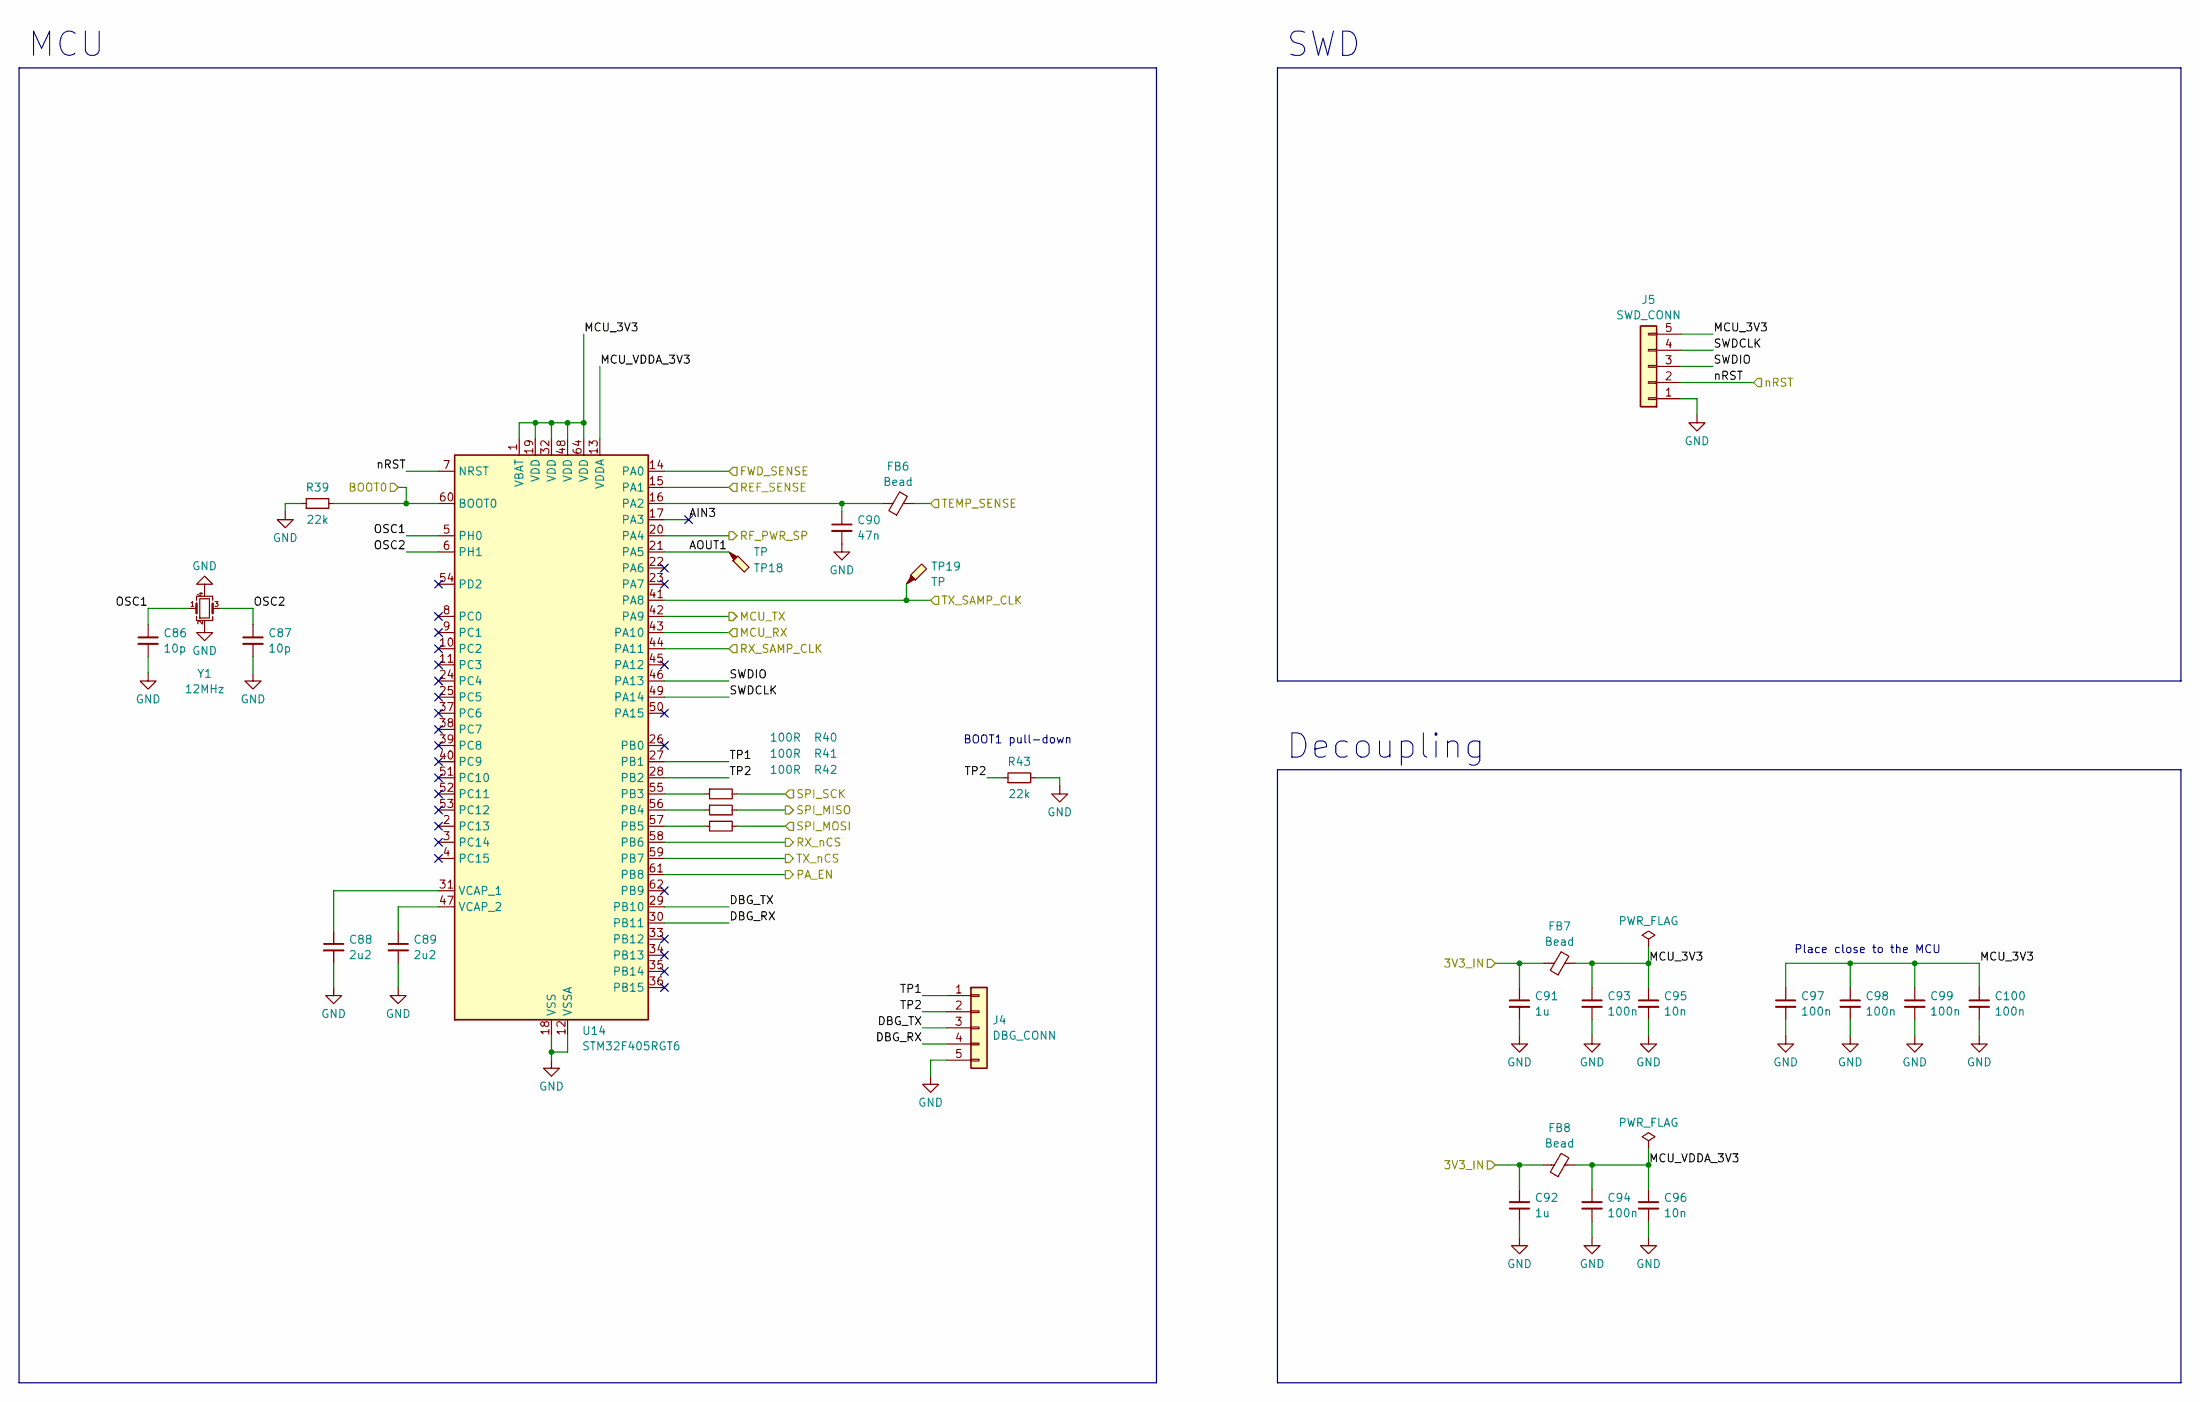
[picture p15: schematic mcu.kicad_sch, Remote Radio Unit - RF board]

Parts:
C86, C87: 10p; C_0603_1608Metric; MPN 06035A100JAT2A
C88, C89: 2u2; C_0603_1608Metric; MPN GRM188R61H225ME11J
C90: 47n; C_0603_1608Metric; MPN C0603C473K5RACTU
C91, C92: 1u; C_0603_1608Metric; MPN CL10B105KB8NQNC
C93, C94, C97, C98, C99, C100: 100n; C_0603_1608Metric; MPN C0603C104M5RAC7411
C95, C96: 10n; C_0603_1608Metric; MPN C0603C103K5RAC7081
FB6, FB7, FB8: Bead; L_0603_1608Metric; MPN BLM18KG601SH1D
J4: DBG_CONN; PinHeader_1x05_P2.54mm_Vertical_SMD_Pin1Left; MPN TSM-105-01-T-SV-TR
J5: SWD_CONN; PinHeader_1x05_P2.54mm_Vertical_SMD_Pin1Left; MPN TSM-105-01-T-SV-TR
R39, R43: 22k; R_0603_1608Metric; MPN CRGCQ0603J22K
R40, R41, R42: 100R; R_0603_1608Metric; MPN CRCW0603100RFKECC
TP18, TP19: TP; TestPoint_Pad_D1.5mm
U14: STM32F405RGT6; LQFP-64_10x10mm_P0.5mm; MPN STM32F405RGT6
Y1: 12MHz; Crystal_SMD_3225-4Pin_3.2x2.5mm; MPN ECS-120-12-33-AEN-TR

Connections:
/Exciter/3.3V_IN: C91.1, C92.1, FB7.1, FB8.1; also elsewhere on the board
/FWD_SENSE: U14.14 (PA0); also elsewhere on the board
/Interface/BOOT0: R39.2, U14.60 (BOOT0); also elsewhere on the board
/Interface/MCU_RX: U14.43 (PA10); also elsewhere on the board
/Interface/MCU_TX: U14.42 (PA9); also elsewhere on the board
/Interface/TEMP_SENSE: FB6.2; also elsewhere on the board
/MCU/AIN3: U14.17 (PA3)
/MCU/AOUT1: TP18.1, U14.21 (PA5)
/MCU/DBG_RX: J4.4, U14.30 (PB11)
/MCU/DBG_TX: J4.3, U14.29 (PB10)
/MCU/MCU_3V3: C93.1, C95.1, C97.1, C98.1, C99.1, C100.1, FB7.2, J5.5, U14.1 (VBAT), U14.19 (VDD), U14.32 (VDD), U14.48 (VDD), U14.64 (VDD)
/MCU/MCU_VDDA_3V3: C94.1, C96.1, FB8.2, U14.13 (VDDA)
/MCU/OSC1: C86.1, U14.5 (PH0), Y1.1
/MCU/OSC2: C87.1, U14.6 (PH1), Y1.3
/MCU/PA_EN: U14.61 (PB8); also elsewhere on the board
/MCU/RF_PWR_SP: U14.20 (PA4); also elsewhere on the board
/MCU/SWDCLK: J5.4, U14.49 (PA14)
/MCU/SWDIO: J5.3, U14.46 (PA13)
/MCU/TP1: J4.1, U14.27 (PB1)
/MCU/TP2: J4.2, R43.1, U14.28 (PB2)
/REF_SENSE: U14.15 (PA1); also elsewhere on the board
/RX_SAMP_CLK: U14.44 (PA11); also elsewhere on the board
/RX_nCS: U14.58 (PB6); also elsewhere on the board
/SPI_MISO: R41.2; also elsewhere on the board
/SPI_MOSI: R42.2; also elsewhere on the board
/SPI_SCK: R40.2; also elsewhere on the board
/TX_SAMP_CLK: TP19.1, U14.41 (PA8); also elsewhere on the board
/TX_nCS: U14.59 (PB7); also elsewhere on the board
/nRST: J5.2, U14.7 (NRST); also elsewhere on the board
GND: C86.2, C87.2, C88.2, C89.2, C90.2, C91.2, C92.2, C93.2, C94.2, C95.2, C96.2, C97.2, C98.2, C99.2, C100.2, J4.5, J5.1, R39.1, R43.2, U14.12 (VSSA), U14.18 (VSS), U14.63 (VSS), Y1.2, Y1.4; also elsewhere on the board
unnamed: C90.1, FB6.1, U14.16 (PA2)
unnamed: R40.1, U14.55 (PB3)
unnamed: R41.1, U14.56 (PB4)
unnamed: R42.1, U14.57 (PB5)
unnamed: C88.1, U14.31 (VCAP_1)
unnamed: C89.1, U14.47 (VCAP_2)

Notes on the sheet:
MCU
Place close to the MCU
BOOT1 pull-down
SWD
Decoupling

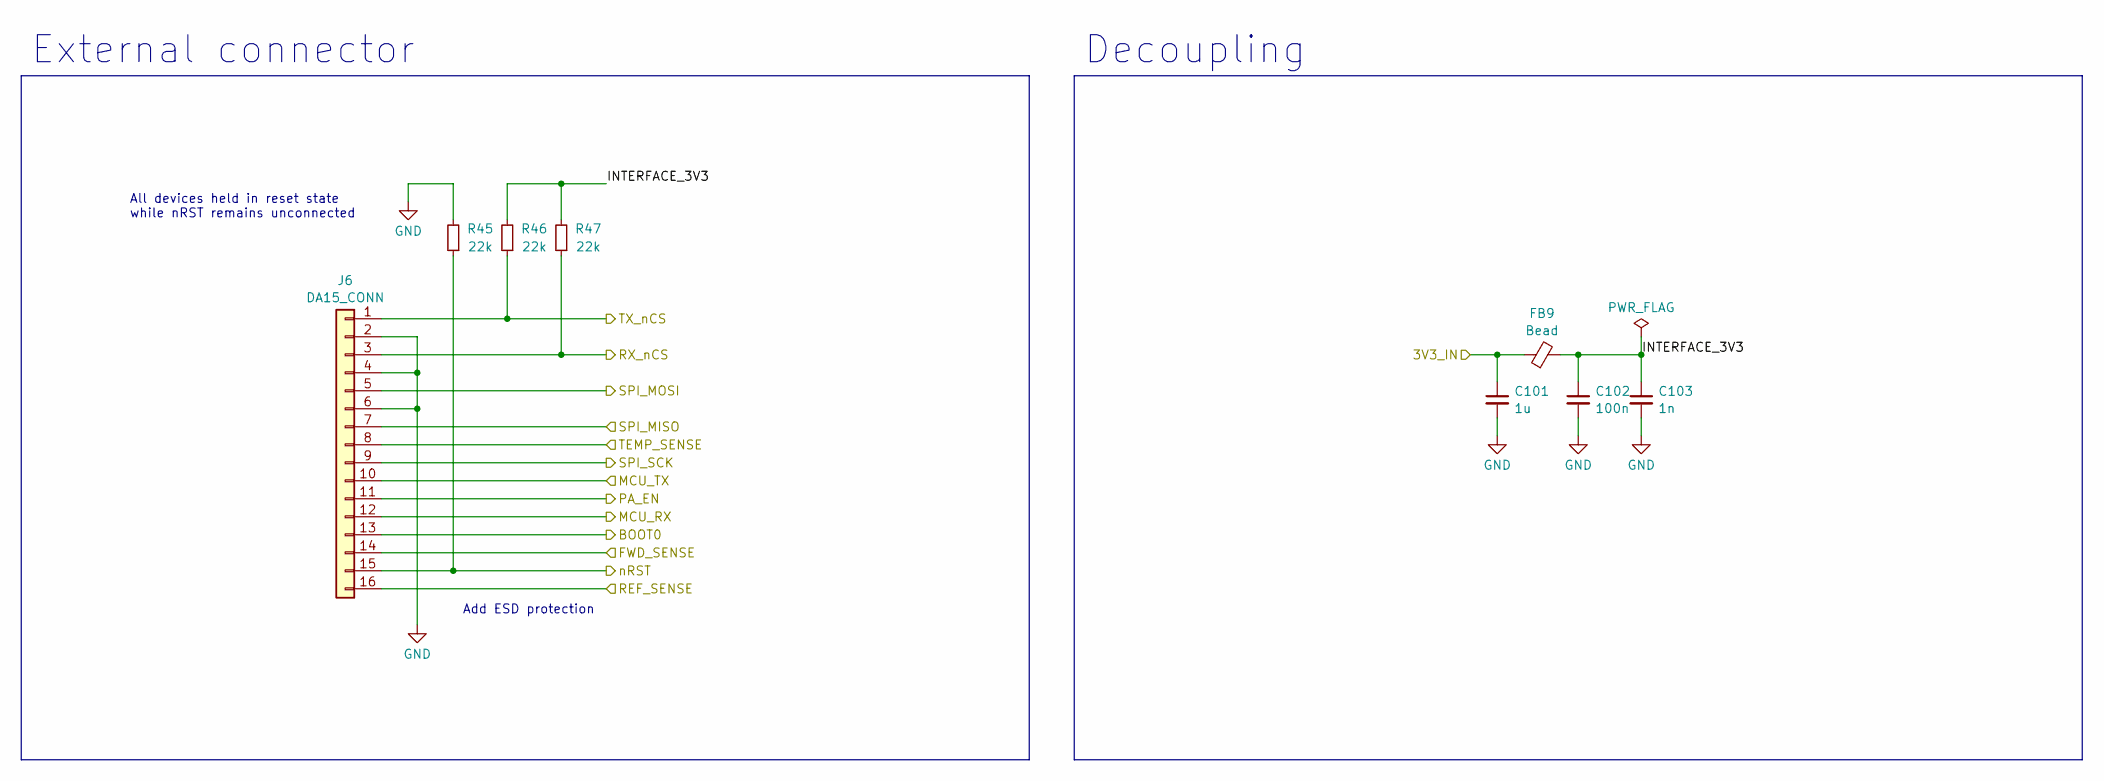
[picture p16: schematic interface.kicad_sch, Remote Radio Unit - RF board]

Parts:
C101: 1u; C_0603_1608Metric; MPN CL10B105KB8NQNC
C102: 100n; C_0603_1608Metric; MPN C0603C104M5RAC7411
C103: 1n; C_0603_1608Metric; MPN C0603C102J5GAC7411
FB9: Bead; L_0603_1608Metric; MPN BLM18KG601SH1D
J6: DA15_CONN; PinHeader_2x08_P2.54mm_Vertical_SMD; MPN TSM-108-01-L-DV-P-TR
R45, R46, R47: 22k; R_0603_1608Metric; MPN CRGCQ0603J22K

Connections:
/Exciter/3.3V_IN: C101.1, FB9.1; also elsewhere on the board
/FWD_SENSE: J6.14; also elsewhere on the board
/Interface/BOOT0: J6.13; also elsewhere on the board
/Interface/INTERFACE_3V3: C102.1, C103.1, FB9.2, R46.2, R47.2
/Interface/MCU_RX: J6.12; also elsewhere on the board
/Interface/MCU_TX: J6.10; also elsewhere on the board
/Interface/PA_EN: J6.11; also elsewhere on the board
/Interface/TEMP_SENSE: J6.8; also elsewhere on the board
/REF_SENSE: J6.16; also elsewhere on the board
/RX_nCS: J6.3, R47.1; also elsewhere on the board
/SPI_MISO: J6.7; also elsewhere on the board
/SPI_MOSI: J6.5; also elsewhere on the board
/SPI_SCK: J6.9; also elsewhere on the board
/TX_nCS: J6.1, R46.1; also elsewhere on the board
/nRST: J6.15, R45.1; also elsewhere on the board
GND: C101.2, C102.2, C103.2, J6.2, J6.4, J6.6, R45.2; also elsewhere on the board

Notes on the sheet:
Decoupling
External connector
All devices held in reset state while nRST remains unconnected
Add ESD protection

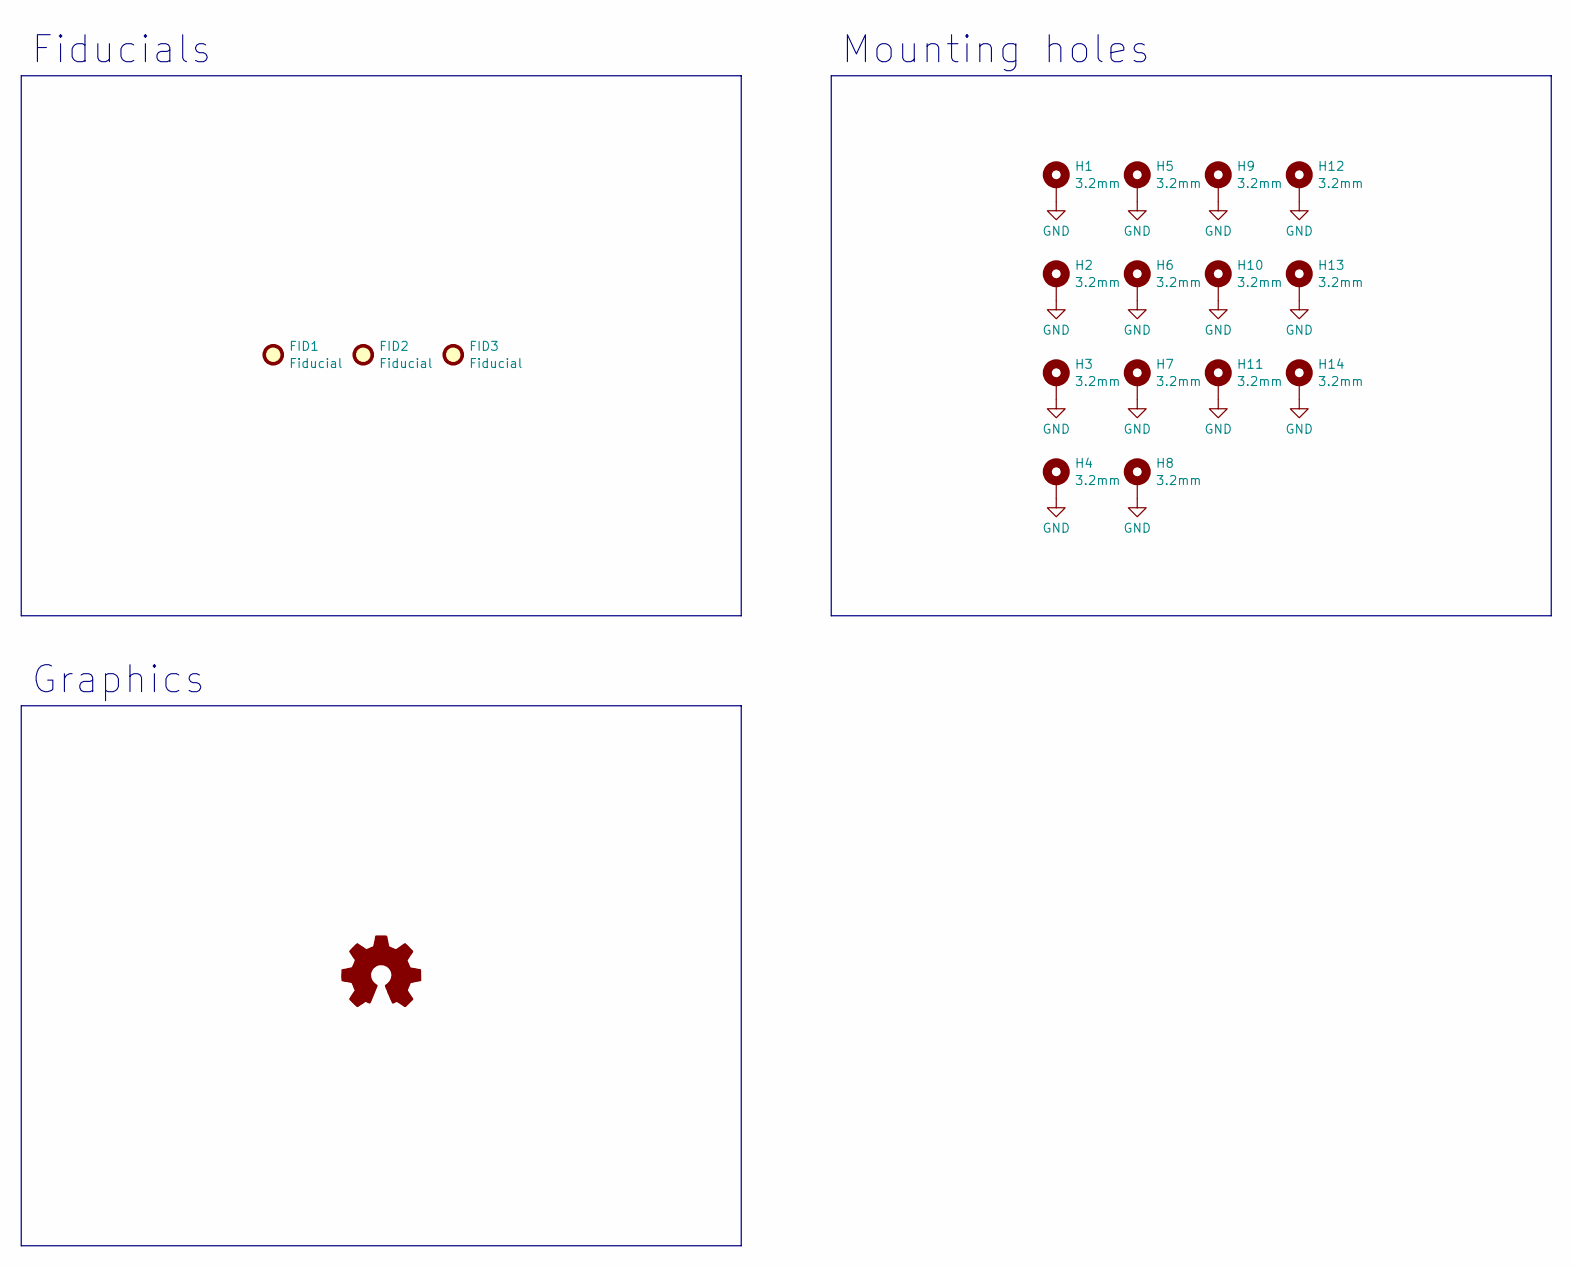
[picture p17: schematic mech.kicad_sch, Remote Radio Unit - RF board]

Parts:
FID1, FID2, FID3: Fiducial; Fiducial_0.75mm_Mask1.5mm
H1, H2, H3, H4, H5, H6, H7, H8, H9, H10, H11, H12, H13, H14: 3.2mm; MountingHole_3.2mm_M3_Pad_Via

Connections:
GND: H1.1, H2.1, H3.1, H4.1, H5.1, H6.1, H7.1, H8.1, H9.1, H10.1, H11.1, H12.1, H13.1, H14.1; also elsewhere on the board

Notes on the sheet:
Mounting holes
Graphics
Fiducials

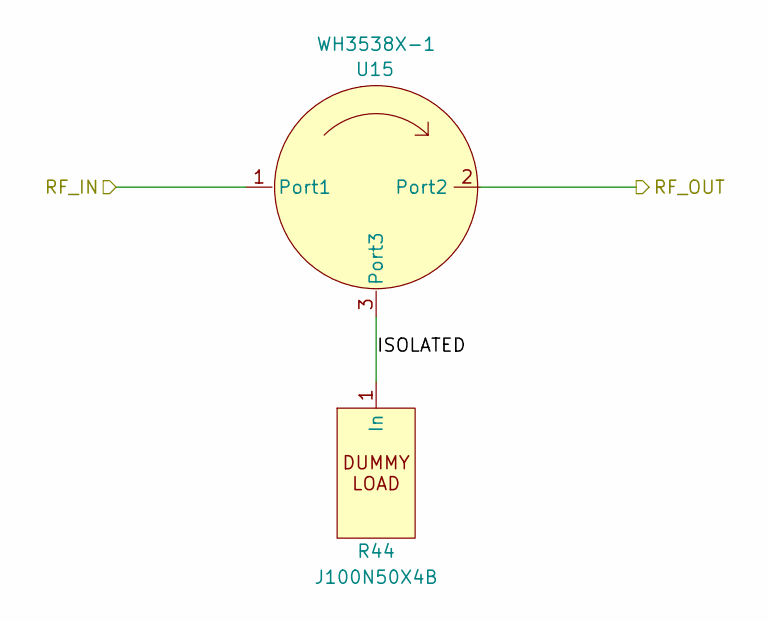
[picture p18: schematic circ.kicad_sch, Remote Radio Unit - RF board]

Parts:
R44: J100N50X4B; HALF_FLANGE_DUMMY_LOAD; MPN J100N50X4B
U15: WH3538X-1; CIRC_H08; MPN WH3538X-1

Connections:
/Circulator/ISOLATED: R44.1 (In), U15.3 (Port3)
/Circulator/RF_IN: U15.1 (Port1); also elsewhere on the board
/Circulator/RF_OUT: U15.2 (Port2); also elsewhere on the board

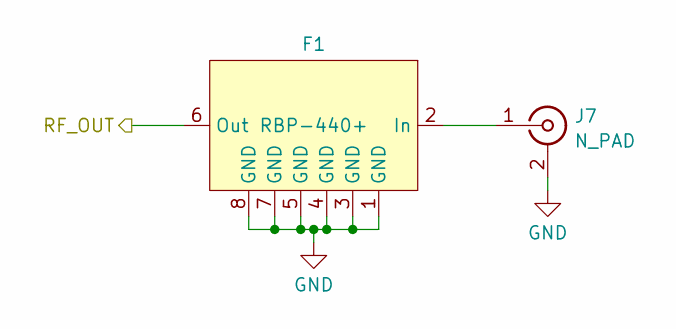
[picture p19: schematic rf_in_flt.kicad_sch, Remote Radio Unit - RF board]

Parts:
F1: RBP-440+; RBP_CASE; MPN RBP-440+
J7: N_PAD; SMA_Samtec_SMA-J-P-X-ST-EM1_EdgeMount

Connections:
/RF input filter/RF_OUT: F1.6 (Out); also elsewhere on the board
GND: F1.1 (GND), F1.3 (GND), F1.4 (GND), F1.5 (GND), F1.7 (GND), F1.8 (GND), J7.2 (Ext); also elsewhere on the board
unnamed: F1.2 (In), J7.1 (In)

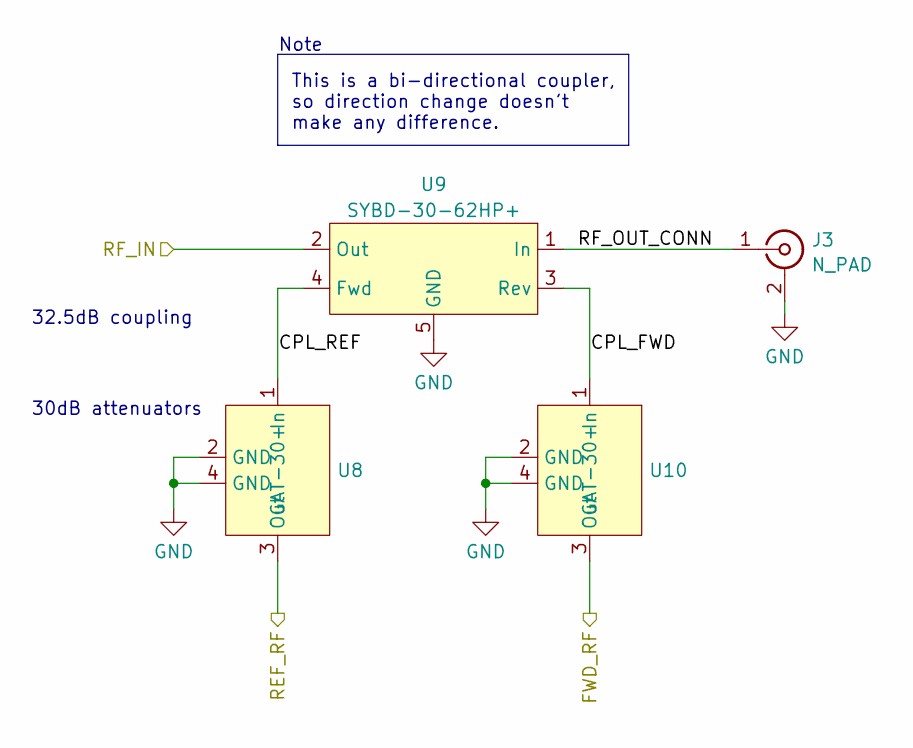
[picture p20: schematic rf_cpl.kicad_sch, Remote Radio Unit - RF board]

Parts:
J3: N_PAD; SMA_Samtec_SMA-J-P-X-ST-EM1_EdgeMount
U8, U10: GAT-30+; GAT-30_LAND; MPN 139-GAT-30+
U9: SYBD-30-62HP+; SYBD-30_LAND; MPN SYBD-30-62HP+

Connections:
/Circulator/RF_OUT: U9.2 (Out); also elsewhere on the board
/RF coupler/CPL_FWD: U9.3 (Rev), U10.1 (In)
/RF coupler/CPL_REF: U8.1 (In), U9.4 (Fwd)
/RF coupler/FWD_RF: U10.3 (Out); also elsewhere on the board
/RF coupler/REF_RF: U8.3 (Out); also elsewhere on the board
/RF coupler/RF_OUT_CONN: J3.1 (In), U9.1 (In)
GND: J3.2 (Ext), U8.2 (GND), U8.4 (GND), U9.5 (GND), U10.2 (GND), U10.4 (GND); also elsewhere on the board

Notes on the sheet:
Note
30dB attenuators
This is a bi-directional coupler, so direction change doesn't make any difference.
32.5dB coupling

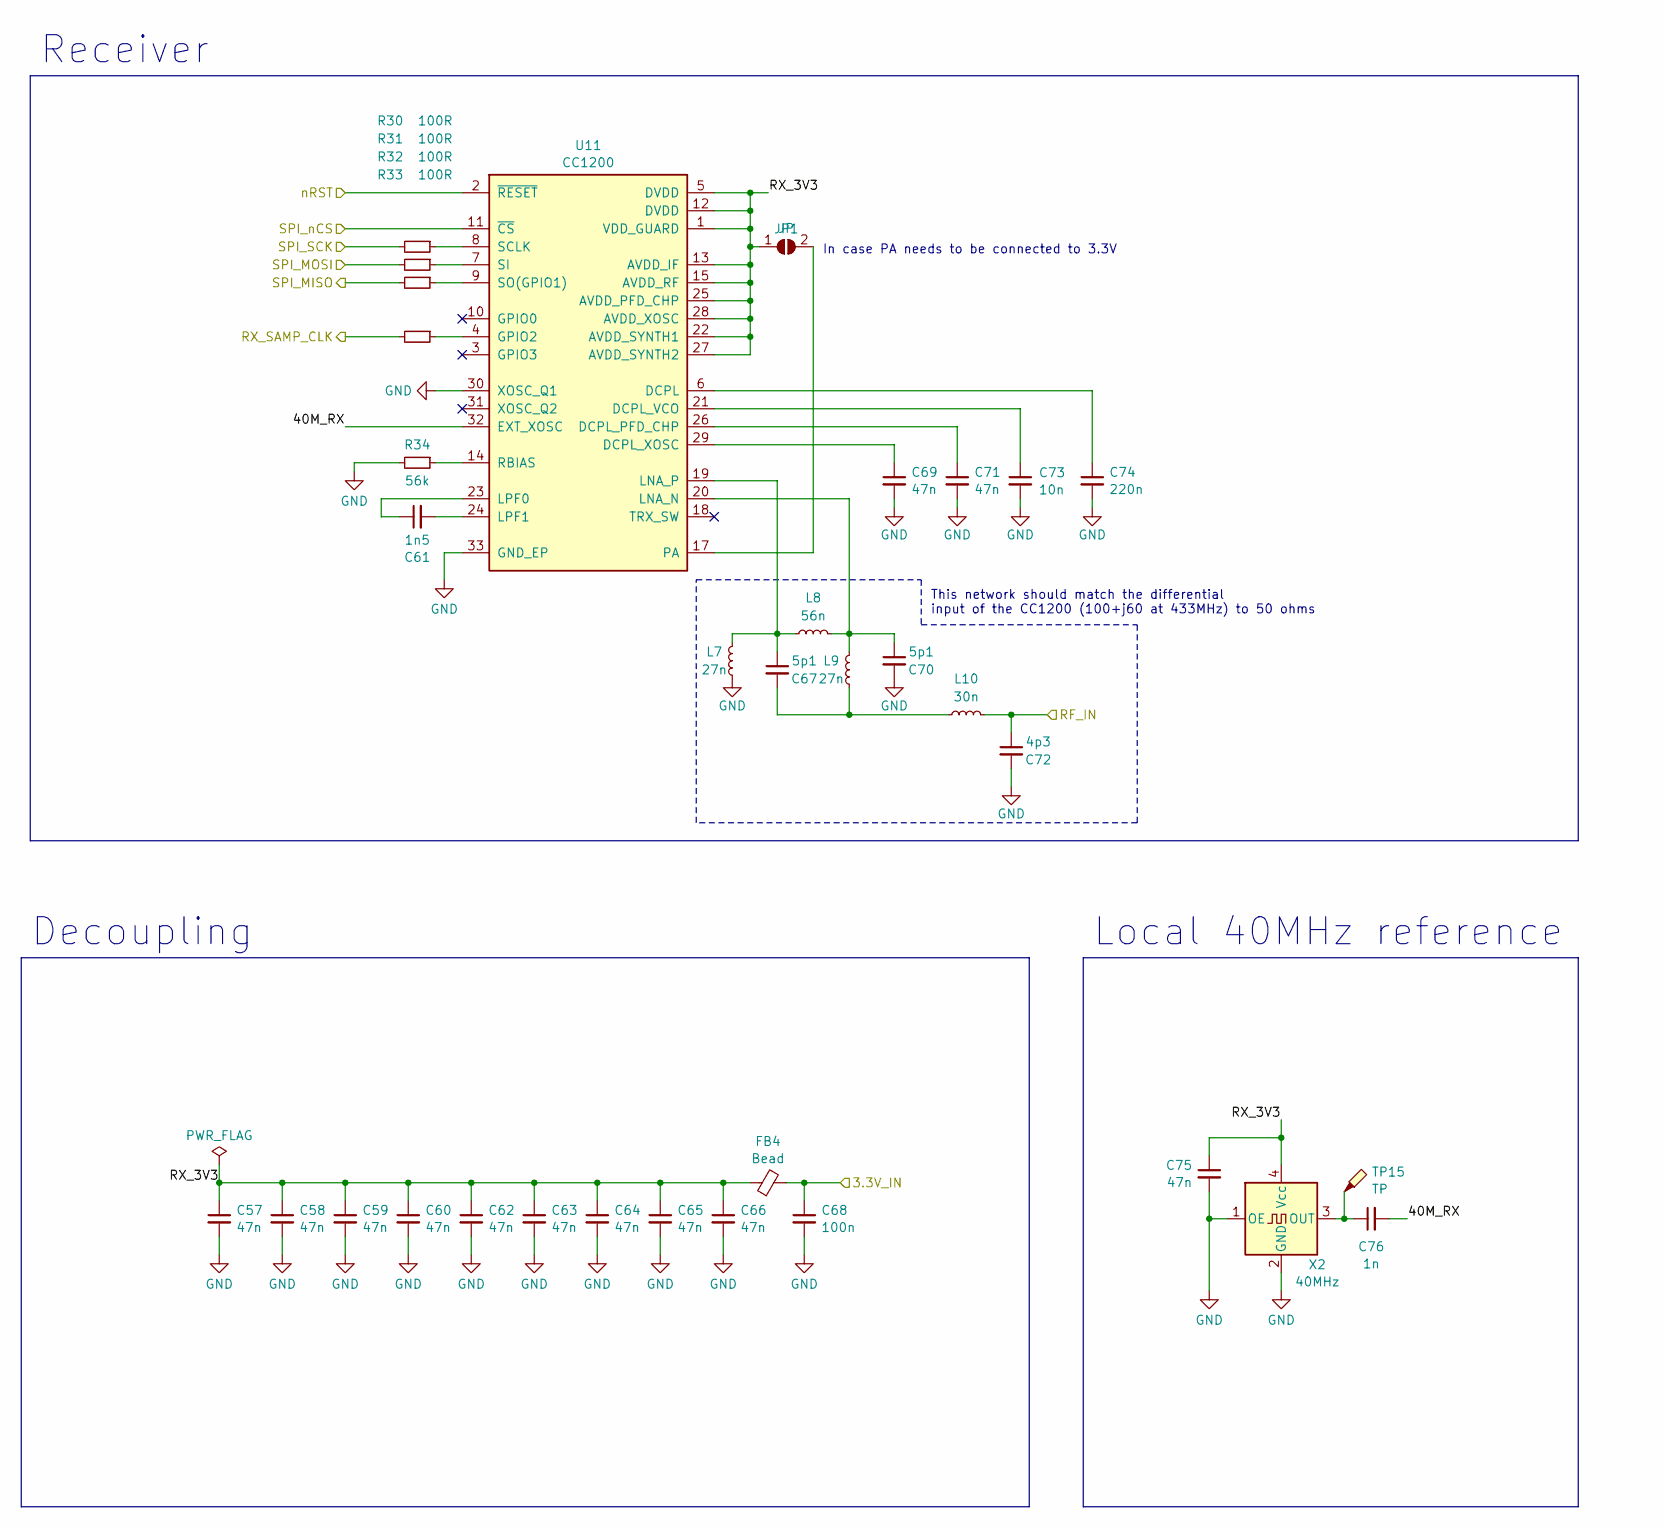
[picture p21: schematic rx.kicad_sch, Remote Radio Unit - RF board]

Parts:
C57, C58, C59, C60, C62, C63, C64, C65, C66, C69, C71, C75: 47n; C_0603_1608Metric; MPN C0603C473K5RACTU
C61: 1n5; C_0603_1608Metric; MPN GRM1885C1H152JA01D
C67, C70: 5p1; C_0603_1608Metric; MPN CC0603CRNPO9BN5R1
C68: 100n; C_0603_1608Metric; MPN C0603C104M5RAC7411
C72: 4p3; C_0603_1608Metric; MPN CBR06C439C5GAC
C73: 10n; C_0603_1608Metric; MPN C0603C103K5RAC7081
C74: 220n; C_0603_1608Metric; MPN C0603C224K4RACTU
C76: 1n; C_0603_1608Metric; MPN C0603C102J5GAC7411
FB4: Bead; L_0603_1608Metric; MPN BLM18KG601SH1D
JP1: JP; SolderJumper-2_P1.3mm_Open_TrianglePad1.0x1.5mm
L7, L9: 27n; L_0603_1608Metric; MPN LQW18AN27NG00D
L8: 56n; L_0603_1608Metric; MPN 81-LQW18AN56NG00D
L10: 30n; L_0603_1608Metric; MPN LQW18AN30NG00D
R30, R31, R32, R33: 100R; R_0603_1608Metric; MPN CRCW0603100RFKECC
R34: 56k; R_0603_1608Metric; MPN CRGCQ0603F56K
TP15: TP; TestPoint_Pad_D1.5mm
U11: CC1200; QFN-32-1EP_5x5mm_P0.5mm_EP3.45x3.45mm; MPN CC1200RHBR
X2: 40MHz; Oscillator_SMD_SeikoEpson_SG210-4Pin_2.5x2.0mm; MPN FT2MNTUM-40.0-T1

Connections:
/Exciter/3.3V_IN: C68.1, FB4.2; also elsewhere on the board
/RF input filter/RF_OUT: C72.1, L10.1; also elsewhere on the board
/RX_SAMP_CLK: R33.2; also elsewhere on the board
/RX_nCS: U11.11 (~CS); also elsewhere on the board
/Receiver/40M_RX: C76.2, U11.32 (EXT_XOSC)
/Receiver/RX_3V3: C57.1, C58.1, C59.1, C60.1, C62.1, C63.1, C64.1, C65.1, C66.1, C75.1, FB4.1, JP1.1 (A), U11.1 (VDD_GUARD), U11.5 (DVDD), U11.12 (DVDD), U11.13 (AVDD_IF), U11.15 (AVDD_RF), U11.22 (AVDD_SYNTH1), U11.25 (AVDD_PFD_CHP), U11.27 (AVDD_SYNTH2), U11.28 (AVDD_XOSC), X2.4 (Vcc)
/SPI_MISO: R32.2; also elsewhere on the board
/SPI_MOSI: R31.2; also elsewhere on the board
/SPI_SCK: R30.2; also elsewhere on the board
/nRST: U11.2 (~RESET); also elsewhere on the board
GND: C57.2, C58.2, C59.2, C60.2, C62.2, C63.2, C64.2, C65.2, C66.2, C68.2, C69.2, C70.2, C71.2, C72.2, C73.2, C74.2, C75.2, L7.2, R34.2, U11.30 (XOSC_Q1), U11.33 (GND_EP), X2.1 (OE), X2.2 (GND); also elsewhere on the board
unnamed: C67.2, L9.2, L10.2
unnamed: JP1.2 (B), U11.17 (PA)
unnamed: C74.1, U11.6 (DCPL)
unnamed: C71.1, U11.26 (DCPL_PFD_CHP)
unnamed: C73.1, U11.21 (DCPL_VCO)
unnamed: C69.1, U11.29 (DCPL_XOSC)
unnamed: R33.1, U11.4 (GPIO2)
unnamed: C70.1, L8.1, L9.1, U11.20 (LNA_N)
unnamed: C67.1, L7.1, L8.2, U11.19 (LNA_P)
unnamed: C61.1, U11.23 (LPF0)
unnamed: C61.2, U11.24 (LPF1)
unnamed: R34.1, U11.14 (RBIAS)
unnamed: R30.1, U11.8 (SCLK)
unnamed: R31.1, U11.7 (SI)
unnamed: R32.1, U11.9 (SO(GPIO1))
unnamed: C76.1, TP15.1, X2.3 (OUT)

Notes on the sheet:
Local 40MHz reference
Decoupling
Receiver
This network should match the differential input of the CC1200 (100+j60 at 433MHz) to 50 ohms
In case PA needs to be connected to 3.3V

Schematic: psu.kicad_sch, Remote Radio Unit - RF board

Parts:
C26, C27, C30: 100u/50V; CP_Elec_8x10.5; MPN 50SEV100M8X10.5
C28, C29: 100n; C_0603_1608Metric; MPN C0603C104M5RAC7411
C31, C32: 22u/6.3V; C_0603_1608Metric; MPN GRM188R60J226MEA0J
D6, D7: B160-13-F; D_SMA; MPN B160-13-F
J2: 13.8V; TestPoint_Pad_D3.0mm
R23: 100k; R_0603_1608Metric; MPN CRCW0603100KFKEAC
TP11, TP12, TP13: TP; TestPoint_Pad_D1.5mm
U5: KF33BDT; TO-252-2; MPN 511-KF33BDT-TR
U6: KF50BDT; TO-252-2; MPN 511-KF50BDT-TR

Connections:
/Exciter/3.3V_IN: C31.2, D6.2 (A), TP12.1, U5.3 (VO); also elsewhere on the board
/Power supply/5V_OUT: C32.2, D7.2 (A), TP13.1, U6.3 (VO); also elsewhere on the board
/Power supply/13.8V_OUT: C26.1, C27.1, C28.1, C29.1, C30.1, D6.1 (K), D7.1 (K), J2.1, R23.1, TP11.1, U5.1 (VI), U6.1 (VI); also elsewhere on the board
GND: C26.2, C27.2, C28.2, C29.2, C30.2, C31.1, C32.1, R23.2, U5.2 (GND), U6.2 (GND); also elsewhere on the board

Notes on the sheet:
Voltage reg.

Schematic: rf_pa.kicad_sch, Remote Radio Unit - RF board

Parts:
C1, C2, C3, C7, C9, C13, C14: 100n; C_0603_1608Metric; MPN C0603C104M5RAC7411
C4: 3n9; C_0603_1608Metric; MPN GCM1885C1H392JA16J; not fitted
C5: 3n9; C_0603_1608Metric; MPN GCM1885C1H392JA16J
C6, C15: 1u; C_0603_1608Metric; MPN CL10B105KB8NQNC
C8, C11, C22: 1n; C_0603_1608Metric; MPN C0603C102J5GAC7411
C10, C19: 10n; C_0603_1608Metric; MPN C0603C103K5RAC7081
C12, C23: 100p; C_0603_1608Metric; MPN VJ0603A101JXAPW1BC
C16: 100u/50V; CP_Elec_8x10.5; MPN 50SEV100M8X10.5
C17, C18, C20: 1p5; C_1206_3216Metric_Pad1.33x1.80mm_HandSolder; MPN 12067A1R5CAT2A
C21: 8p2; C_1206_3216Metric_Pad1.33x1.80mm_HandSolder; MPN 12067A8R2BAT2A
C24: DNP; C_1206_3216Metric_Pad1.33x1.80mm_HandSolder; not fitted
C25: 2p7; C_1206_3216Metric_Pad1.33x1.80mm_HandSolder; MPN 12062A2R7CAT2A
D1, D2: B160-13-F; D_SMA; MPN B160-13-F
D3: MM3Z4V7S; D_SOD-323; MPN MM3Z4V7ST1G
D4, D5: SS1P4L; DO-220AA-SMP; MPN SS1P4LHM3/84A
FB1, FB2: Bead; L_0603_1608Metric; MPN BLM18KG601SH1D
J1: LMT87LPM; PinHeader_1x03_P2.54mm_Vertical_SMD_Pin1Left; MPN TSM-103-01-T-SV-TR
L1: 24nH; aircoil_L; not fitted
L2: 24nH; aircoil_R; not fitted
Q1, Q2: BSS138; SOT-23; MPN BSS138P,215
Q3: NP100P04PDG; TO-263-2; MPN NP100P04PDG-E1-AY
R1: 7k5; R_0603_1608Metric; MPN RK73H1JTTD7501F
R2: 22k; R_0603_1608Metric; MPN CRGCQ0603J22K
R3: 4k7; R_0603_1608Metric; MPN RK73B1JRTTD472J
R4, R11, R19, R22: 100k; R_0603_1608Metric; MPN CRCW0603100KFKEAC
R5, R9, R10, R12, R18, R20: 10k; R_0603_1608Metric; MPN RT0603FRE0710KL
R6: 240R; R_0603_1608Metric; MPN WR06X2400FTL
R7: 1k; R_0603_1608Metric; MPN RC0603FR-071KL
R8, R13, R16, R17: 100R; R_0603_1608Metric; MPN CRCW0603100RFKECC
R14, R21: 12k; R_0603_1608Metric; MPN CRCW060312K0FKEAC
R15: 2k2; R_0603_1608Metric; MPN CRCW06032K20FKEAC
TP1, TP2, TP3, TP4, TP5, TP6, TP7, TP8, TP9, TP10: TP; TestPoint_Pad_D1.5mm
U1: LM317_SOT-223; SOT-223-3_TabPin2; MPN LM317MDCYRG3
U2: LT1013DIDR; SOIC127P600X175-8N; Mouser Part Number 595-LT1013DIDR
U3: TL431; SOT-23; MPN TL431LIBIDBZR
U4: RA60H3847H1; H2M

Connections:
/Circulator/RF_IN: C24.2, C25.1, L2.2; also elsewhere on the board
/Exciter/RF_OUT: U4.1 (In); also elsewhere on the board
/FWD_SENSE: R5.1, TP2.1; also elsewhere on the board
/Interface/PA_EN: R16.1; also elsewhere on the board
/Interface/TEMP_SENSE: J1.2; also elsewhere on the board
/MCU/PA_EN: R17.1; also elsewhere on the board
/MCU/RF_PWR_SP: R1.1; also elsewhere on the board
/Power supply/5V_OUT: C15.1, FB2.1; also elsewhere on the board
/Power supply/13.8V_OUT: C1.1, D1.1 (K), D5.1 (K), Q3.3 (S), R21.2, U1.3 (VI); also elsewhere on the board
/RF PA/PA_OUT: C17.2, C18.1, L1.1, U4.4 (Out)
/RF PA/PA_OUT_2: C20.2, C21.1, L1.2, L2.1
/RF PA/RF_PA_1V1: C9.1, R12.2, R14.2, TP6.1, U2.1 (1IN+)
/RF PA/RF_PA_7V: C7.1, C8.1, FB1.2, R15.2, TP5.1, U2.6 (VCC+)
/RF PA/RF_PA_VDD: C16.1, C19.1, C22.2, C23.1, D4.1 (K), D5.2 (A), Q3.2 (D), R22.1, U4.3 (VDD)
/RF PA/RF_PA_VGG: C10.1, C11.2, C12.1, D3.1 (K), R13.1, U4.2 (VGG)
/RF PA/VGG_RAW: C5.1, R11.2, R13.2, TP3.1, U2.5 (2OUT)
GND: C1.2, C2.2, C3.2, C6.2, C7.2, C8.2, C9.2, C10.2, C11.1, C12.2, C13.1, C14.2, C15.2, C16.2, C17.1, C18.2, C19.2, C20.1, C21.2, C22.1, C23.2, C24.1, C25.2, D3.2 (A), D4.2 (A), J1.3, Q2.2 (S), R2.1, R4.1, R8.1, R12.1, R20.1, R22.2, U2.2 (VCC-), U3.3 (A); also elsewhere on the board
unnamed: C6.1, D1.2 (A), D2.1 (K), FB1.1, R6.2, U1.2 (VO)
unnamed: C3.1, D2.2 (A), R6.1, R7.2, U1.1 (ADJ)
unnamed: C14.1, FB2.2, J1.1
unnamed: Q1.3 (D), Q3.1 (G), R21.1, TP10.1
unnamed: Q1.1 (G), R16.2, R18.2, TP8.1
unnamed: Q1.2 (S), Q2.3 (D), R18.1, R19.2
unnamed: Q2.1 (G), R17.2, R19.1, R20.2, TP9.1
unnamed: R1.2, R2.2, R3.1, TP1.1
unnamed: R7.1, R8.2
unnamed: C4.2, R5.2, R9.2, U2.8 (1IN-)
unnamed: C4.1, R9.1, R10.2, TP4.1, U2.7 (1OUT)
unnamed: C2.1, R3.2, R4.2, U2.3 (2IN+)
unnamed: C5.2, R10.1, R11.1, U2.4 (2IN-)
unnamed: C13.2, R14.1, R15.1, TP7.1, U3.1 (K), U3.2 (REF)

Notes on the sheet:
Voltage reg.
RF PA
Aircoils to be populated manually
Aircoils: 0.8mm silver plated copper wire 3 turns 3.2mm inner dia ~4mm length Resulting inductance should be around 24nH
Supply switching
ALC

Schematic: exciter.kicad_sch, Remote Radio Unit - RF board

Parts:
C33, C34, C35, C36, C37, C39, C40, C41, C42, C44, C45, C50: 47n; C_0603_1608Metric; MPN C0603C473K5RACTU
C38: 1n5; C_0603_1608Metric; MPN GRM1885C1H152JA01D
C43: 100n; C_0603_1608Metric; MPN C0603C104M5RAC7411
C46, C52: 10n; C_0603_1608Metric; MPN C0603C103K5RAC7081
C47: 220n; C_0603_1608Metric; MPN C0603C224K4RACTU
C48: 39p; C_0603_1608Metric; MPN CL10C390JB81PNC
C49: 56p; C_0603_1608Metric; MPN 0603N560F500CT
C51: 2p2; C_0603_1608Metric; MPN CC0603BRNPO9BN2R2
C53: 5p1; C_0603_1608Metric; MPN CC0603CRNPO9BN5R1
C54: 100p; C_0603_1608Metric; MPN VJ0603A101JXAPW1BC
C55: 6p2; C_0603_1608Metric; MPN GRM1885C1H6R2BA01D
C56: 1n; C_0603_1608Metric; MPN C0603C102J5GAC7411
FB3: Bead; L_0603_1608Metric; MPN BLM18KG601SH1D
L3: 56n; L_0603_1608Metric; MPN 81-LQW18AN56NG00D
L4: 15n; L_0603_1608Metric; MPN LQW18AS15NG00D
L5: 43n; L_0603_1608Metric; MPN LQW18AN43NJ00D
L6: 22n; L_0603_1608Metric; MPN LQW18AN22NG00D
R24, R25, R26, R27: 100R; R_0603_1608Metric; MPN CRCW0603100RFKECC
R28: 56k; R_0603_1608Metric; MPN CRGCQ0603F56K
R29: 18R; R_0603_1608Metric; MPN RC0603FR-0718RL
TP14: TP; TestPoint_Pad_D1.5mm
U7: CC1200; QFN-32-1EP_5x5mm_P0.5mm_EP3.45x3.45mm; MPN CC1200RHBR
X1: 40MHz; Oscillator_SMD_SeikoEpson_SG210-4Pin_2.5x2.0mm; MPN FT2MNTUM-40.0-T1

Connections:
/Exciter/3.3V_IN: C43.1, FB3.2; also elsewhere on the board
/Exciter/40M_TX: C56.2, U7.32 (EXT_XOSC)
/Exciter/EXCITER_3V3: C33.1, C34.1, C35.1, C36.1, C37.1, C39.1, C40.1, C41.1, C42.1, C49.1, C50.1, C52.1, C54.1, FB3.1, R29.2, U7.1 (VDD_GUARD), U7.5 (DVDD), U7.12 (DVDD), U7.13 (AVDD_IF), U7.15 (AVDD_RF), U7.22 (AVDD_SYNTH1), U7.25 (AVDD_PFD_CHP), U7.27 (AVDD_SYNTH2), U7.28 (AVDD_XOSC), X1.4 (Vcc)
/Exciter/RF_OUT: L6.1; also elsewhere on the board
/SPI_MISO: R26.2; also elsewhere on the board
/SPI_MOSI: R25.2; also elsewhere on the board
/SPI_SCK: R24.2; also elsewhere on the board
/TX_SAMP_CLK: R27.2; also elsewhere on the board
/TX_nCS: U7.11 (~CS); also elsewhere on the board
/nRST: U7.2 (~RESET); also elsewhere on the board
GND: C33.2, C34.2, C35.2, C36.2, C37.2, C39.2, C40.2, C41.2, C42.2, C43.2, C44.2, C45.2, C46.2, C47.2, C50.2, C52.2, C53.2, C54.2, C55.2, R28.2, U7.19 (LNA_P), U7.20 (LNA_N), U7.30 (XOSC_Q1), U7.33 (GND_EP), X1.1 (OE), X1.2 (GND); also elsewhere on the board
unnamed: C48.1, C51.2, L4.2
unnamed: C49.2, L3.1, R29.1
unnamed: C51.1, C53.1, L4.1, L5.2
unnamed: C55.1, L5.1, L6.2
unnamed: C47.1, U7.6 (DCPL)
unnamed: C45.1, U7.26 (DCPL_PFD_CHP)
unnamed: C46.1, U7.21 (DCPL_VCO)
unnamed: C44.1, U7.29 (DCPL_XOSC)
unnamed: R27.1, U7.4 (GPIO2)
unnamed: C38.1, U7.23 (LPF0)
unnamed: C38.2, U7.24 (LPF1)
unnamed: C48.2, L3.2, U7.17 (PA)
unnamed: R28.1, U7.14 (RBIAS)
unnamed: R24.1, U7.8 (SCLK)
unnamed: R25.1, U7.7 (SI)
unnamed: R26.1, U7.9 (SO(GPIO1))
unnamed: C56.1, TP14.1, X1.3 (OUT)

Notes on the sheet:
Local 40MHz reference
Decoupling
Exciter

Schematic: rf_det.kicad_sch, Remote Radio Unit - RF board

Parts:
C77: 1u; C_0603_1608Metric; MPN CL10B105KB8NQNC
C78, C80, C83: 100n; C_0603_1608Metric; MPN C0603C104M5RAC7411
C79, C81, C82, C84, C85: 1n; C_0603_1608Metric; MPN C0603C102J5GAC7411
FB5: Bead; L_0603_1608Metric; MPN BLM18KG601SH1D
R35, R37: 52R3; R_0603_1608Metric; MPN CR0603-FX-52R3ELF
R36, R38: 499R; R_0603_1608Metric; MPN CRCW0603499RFKEA
TP16, TP17: TP; TestPoint_Pad_D1.5mm
U12, U13: AD8318; QFN65P400X400X100-17N; Mouser Part Number 584-AD8318ACPZ-R7

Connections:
/FWD_SENSE: TP16.1, U12.6 (VOUT), U12.7 (VSET); also elsewhere on the board
/Power supply/5V_OUT: C77.1, FB5.1; also elsewhere on the board
/REF_SENSE: TP17.1, U13.6 (VOUT), U13.7 (VSET); also elsewhere on the board
/RF coupler/FWD_RF: C81.1, R35.2; also elsewhere on the board
/RF coupler/REF_RF: C85.1, R37.2; also elsewhere on the board
/RF detectors/RF_DET_5V: C80.1, C82.1, FB5.2, U12.3 (VPSI_2), U12.4 (VPSI), U12.9 (VPSO), U12.16 (ENBL), U13.3 (VPSI_2), U13.4 (VPSI), U13.9 (VPSO), U13.16 (ENBL)
GND: C77.2, C78.2, C79.1, C80.2, C82.2, C83.2, C84.1, R35.1, R36.2, R37.1, R38.2, U12.1 (CMIP_2), U12.2 (CMIP_3), U12.8 (CMOP), U12.11 (CMIP_4), U12.12 (CMIP), U12.17 (EP), U13.1 (CMIP_2), U13.2 (CMIP_3), U13.8 (CMOP), U13.11 (CMIP_4), U13.12 (CMIP), U13.17 (EP); also elsewhere on the board
unnamed: C78.1, U12.5 (CLPF)
unnamed: C81.2, U12.14 (INHI)
unnamed: C79.2, U12.15 (INLO)
unnamed: R36.1, U12.10 (TADJ)
unnamed: C83.1, U13.5 (CLPF)
unnamed: C85.2, U13.14 (INHI)
unnamed: C84.2, U13.15 (INLO)
unnamed: R38.1, U13.10 (TADJ)

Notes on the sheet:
REF power sense
Decoupling
FWD power sense

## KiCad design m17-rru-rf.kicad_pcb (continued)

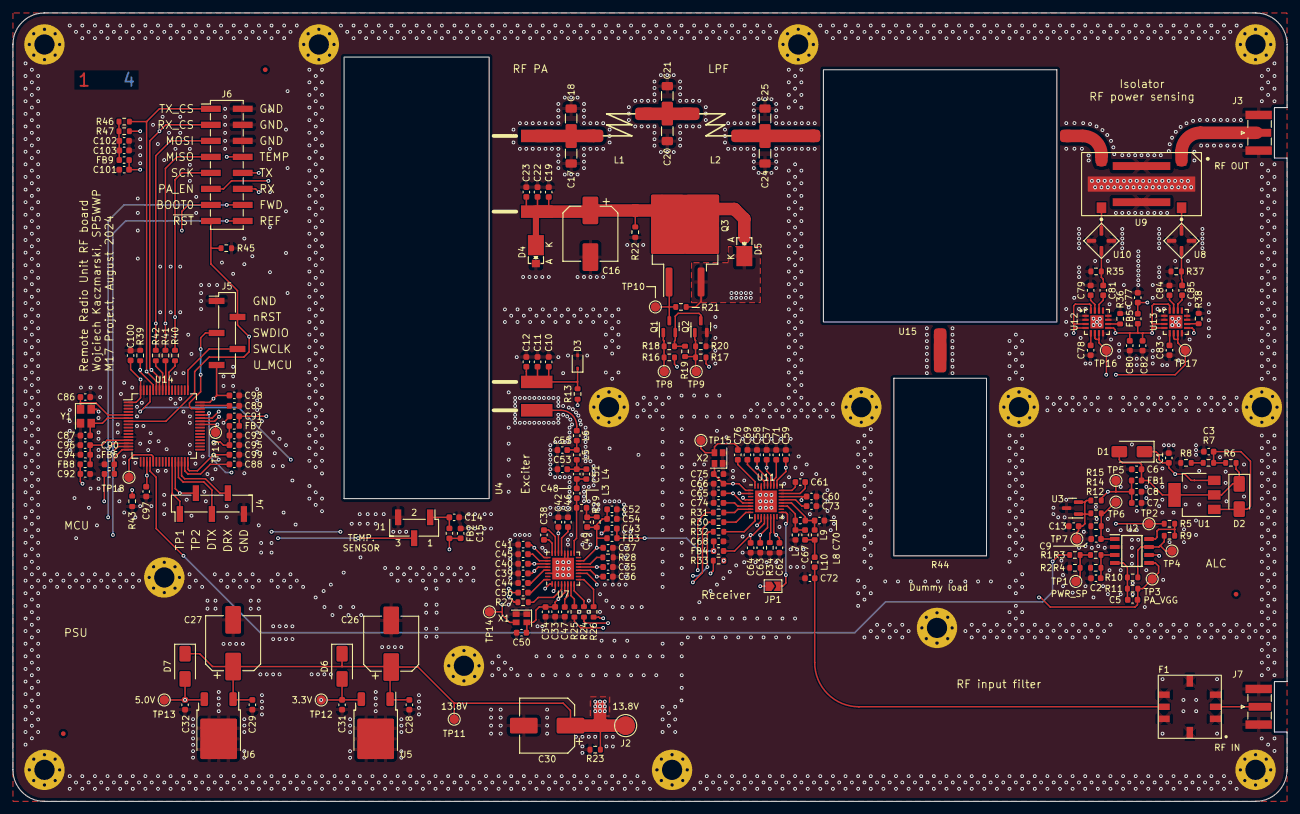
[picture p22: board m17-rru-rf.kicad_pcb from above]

Board: 4 copper layers, 202.0 x 125.0 mm, 241 parts (0 on the bottom side), 117 nets.

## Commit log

2023-10-14 LM317 protection diode location update
    [exciter.kicad_sch, interface.kicad_sch, m17-rru-rf.kicad_pcb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]
2023-10-14 partial PN update
    [exciter.kicad_sch, interface.kicad_sch, mcu.kicad_sch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]
2023-10-14 added missing 40MHz source
    [exciter.kicad_sch, interface.kicad_sch, m17-rru-rf.kicad_pcb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]
2023-10-15 caps' val update
    40MHz TCXO's max. output load is 10p||10k
    [exciter.kicad_sch, rx.kicad_sch]
2023-10-15 RF PA's Vgg signal fix
    [psu.kicad_sch, rf_pa.kicad_sch]
2023-10-15 significant updates
    - supply for the detector block changed from 3.3V to 5V
    - minor bugfixes
    [circ.kicad_sch, exciter.kicad_sch, interface.kicad_sch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]
2023-10-15 PN update
    [circ.kicad_sch, exciter.kicad_sch, interface.kicad_sch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]
2023-10-15 date and labels update
    [circ.kicad_sch, exciter.kicad_sch, interface.kicad_sch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]
2023-10-15 `PWR_FLAG`, ERC cleanup
    [exciter.kicad_sch, interface.kicad_sch, m17-rru-rf.kicad_pcb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]
2023-10-16 TP updates, temp sensor added
    [exciter.kicad_sch, interface.kicad_sch, m17-rru-rf.kicad_pcb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]
2023-10-16 started pcb layout
    [m17-rru-rf.kicad_pcb]
2023-10-25 moved around a few components
    [m17-rru-rf.kicad_pcb]
2023-10-26 pcb update
    [m17-rru-rf.kicad_pcb, m17-rru-rf.kicad_sch]
2023-10-27 pcb update - PSU
    [m17-rru-rf.kicad_pcb]
2023-10-28 `DA15_CONN` pinout change
    [interface.kicad_sch, m17-rru-rf.kicad_pcb]
2023-10-30 pcb routing update
    [m17-rru-rf.kicad_pcb]
2023-10-30 silkscreen update
    [m17-rru-rf.kicad_pcb]
2023-10-30 date update
    [circ.kicad_sch, exciter.kicad_sch, interface.kicad_sch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]
2023-10-31 some via fencing
    [circ.kicad_sch, exciter.kicad_sch, interface.kicad_sch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]
2023-11-02 DRU fixes
    [m17-rru-rf.kicad_pcb]
2023-11-02 MPN/PN update
    [circ.kicad_sch, exciter.kicad_sch, interface.kicad_sch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]
2023-11-02 minor silkscreen updates
    [m17-rru-rf.kicad_pcb]
2023-11-02 another silkscreen fix
    [m17-rru-rf.kicad_pcb]
2023-11-03 diode polarization bugfix
    [circ.kicad_sch, exciter.kicad_sch, interface.kicad_sch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]
2023-11-03 small Top copper pour fix
    [m17-rru-rf.kicad_pcb]
2023-11-10 attenuators' PN update
    [circ.kicad_sch, exciter.kicad_sch, interface.kicad_sch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]
2023-12-12 mechanical BOM
2023-12-15 generated BOM doc
    [m17-rru-rf.csv]
2024-01-18 WIP rev B
    - replaced R44-R46 with 22k
    - exposed BOOT0 at the DA15 connector
    - added a testpoint at DAC OUT2
    - added a buffer to the 40MHz reference oscillator
    - removed C2
    - bypassed R5 with a 100nF capacitor
    - changed D5's voltage to 5.1V
    - routed TX_SAMP_CLK
    - changed temperature sensor's supply voltage to 5V
    - added a series of 100p, 1n and 10n capacitors at PA_VGG
    - reduced N-connector cutouts to 2.5mm
    - improved RF output track a little
    [circ.kicad_sch, exciter.kicad_sch, interface.kicad_sch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]
2024-01-18 routed the 40MHz oscillator
    [exciter.kicad_sch, m17-rru-rf.kicad_pcb, m17-rru-rf.kicad_sch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]
2024-01-19 WIP rev B
    - added bleed resistors
    - power supply now uses linear regulators
    - routed RX_SAMP_CLK
    - added some decoupling at RF_PA_VDD
    - added some GND vias here and there
    - updated BOM
    [circ.kicad_sch, exciter.kicad_sch, interface.kicad_sch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]
2024-01-19 L1, L6 - PN update
    [exciter.kicad_sch, m17-rru-rf.csv, m17-rru-rf.kicad_sch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]
2024-01-19 updated PCB render
    [exciter.kicad_sch, m17-rru-rf.kicad_pcb, rf_pa.kicad_sch]
2024-01-19 silkscreen update (U2)
    [m17-rru-rf.kicad_pcb]
2024-01-20 minor footprint updates
    [circ.kicad_sch, exciter.kicad_sch, interface.kicad_sch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]
2024-01-20 BOM typo fix
    [m17-rru-rf.csv]
2024-01-20 minor changes
    footprint name change
    [m17-rru-rf.kicad_pcb, rf_det.kicad_sch, rf_pa.kicad_sch]
2024-01-20 removed extra space
    [rf_det.kicad_sch]
2024-01-20 removed capacitor
    removed cap between the 40MHz source and RX
    [interface.kicad_sch, m17-rru-rf.csv, m17-rru-rf.kicad_pcb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]
2024-01-20 brought back the logo
    [m17-rru-rf.kicad_pcb]
2024-01-21 minor silkscreen update
    [m17-rru-rf.kicad_pcb]
2024-04-04 WIP rev C
    [circ.kicad_sch, exciter.kicad_sch, interface.kicad_sch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]
2024-04-05 Rev C
    - lowpass at RF in
    - lowpass after RF PA
    - pulldown at TP2 (BOOT1)
    - CC1200 clocking fixed
    - PCB render/PDF update
    [m17-rru-rf.kicad_pcb, mech.kicad_sch, rf_in_flt.kicad_sch]
2024-05-05 KiCAD version bump to 8.0.2
    - updated U9 PN
    [circ.kicad_sch, exciter.kicad_sch, interface.kicad_sch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]
2024-05-07 C47/C74 PN update
    [exciter.kicad_sch, m17-rru-rf.kicad_pcb, rx.kicad_sch]
2024-06-03 Update README.md
    new section: flashing the MCU over UART
2024-08-08 design updates
    - migrated to KiCAD 8.0.4
    - updated Vgg Zener diode from 5.1 to 4.7V
    - updated directional coupler's footprint
    - set RF lowpass filter caps' values
    - removed the outdated BOM CSV file
    - updated the PCB render and schematic PDF
    [m17-rru-rf.csv, m17-rru-rf.kicad_pcb, rf_pa.kicad_sch]

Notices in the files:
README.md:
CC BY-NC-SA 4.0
